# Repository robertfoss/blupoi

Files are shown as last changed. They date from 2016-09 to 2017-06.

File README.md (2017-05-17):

blupoi
======

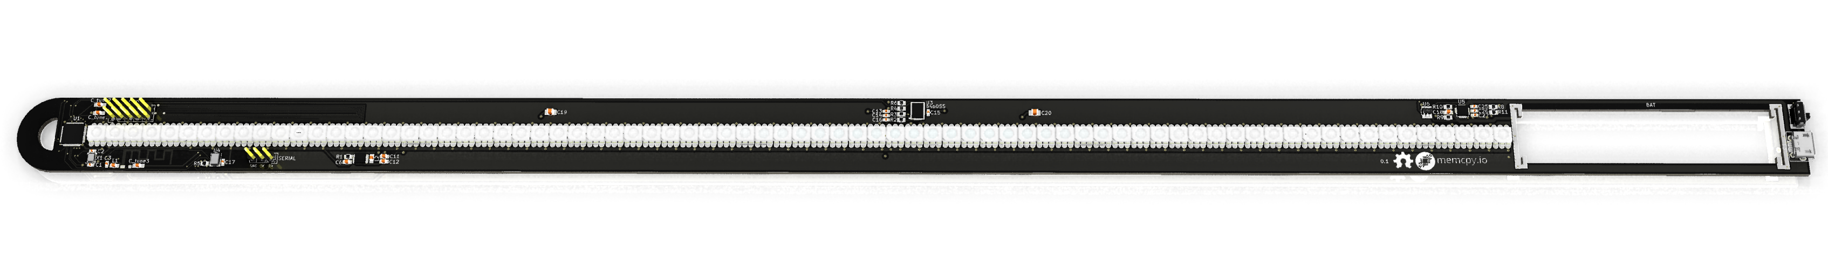
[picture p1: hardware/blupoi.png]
v0.1: render


TODO
----

Changes since v0.3:
 - 1uF 0402 caps not ordered
 * C27 pad has a large via in a pad
 * FIXED: MAX16054 Connect CLEAR to GND if unused.
 * FIXED: SIP32408 Footprint pinout was mirrored
 ? Change battery orientation, since spring should be on the top side but also on the gnd side of BAT
  - Maybe dont since VBAT would end up coming out in a place where it is not useful
 * X1 label covered by hole
 * X1 footprint larger than bom part?
 * C1/C2/C3 footprint is 0603 but bom is 0402
 * SWO header, change part and footprint to have only be connectable the 'right' way

Changes since v0.2:
 * FIXED: Replaced USB connector oval holes with round ones for improved fabricability
 * FIXED: Reflowed filled zones since KiCad somehow did it randomly wrong in v0.2
 * FIXED: R1 Move via further away from pad
 * FIXED: Move USB connector and power button to the side

Changes since v0.1:
 * FIXED: Battery compartment is not quite wide enough.
 * IGNORE: Battery compartment battery spring slot is:
   - 0.5mm too thin, should be 1.6mm
   - 0.5mm too slim, should me 17.75mm
 * FIXED: Spring slots lack copper on the back side
 * FIXED: +/- symbols on the battery silkscreen
 ? IGNORE: battery footprint 180 degrees

 * FIXED: U5/bq24075 EN1 is not pulled down
 * FIXED: U5/bq24075 sysoff turns charging off. Which is should never dd
   - Add separate add some kind of switch between u5 out and vin, controlled by button logic
   - Pull sysoff down
 * Add Load switch like Sip32431 - http://www.vishay.com/docs/66597/sip32431.pdf
   - But ~4.8A at @ 5V
   - SiP32101? No. Is LGA package
   - SiP32408? 3.5A probably ok since no usb port delivers that, and probable no battery either
     - http://www.vishay.com/docs/63717/sip32408.pdf

 * FIXED: Mic port hole is not drilled (hole too small?)
 * FIXED: Mic pads should probably be longer

 * FIXED: Move button footprint slightly closer to edge

 * FIXED: BNO055 pads should probable be longer

 * FIXED: Make logos bigger to make details visible

 * FIXED: Change L2 footprint from 0603 to 1206

 * Vin not connected on 3.3V regulator

 * FIXED: Add silkscreen saying:
   look at you, hacker, a pathetic creature of meat and bone. how can you compare yourself to a perfect immortal machine.

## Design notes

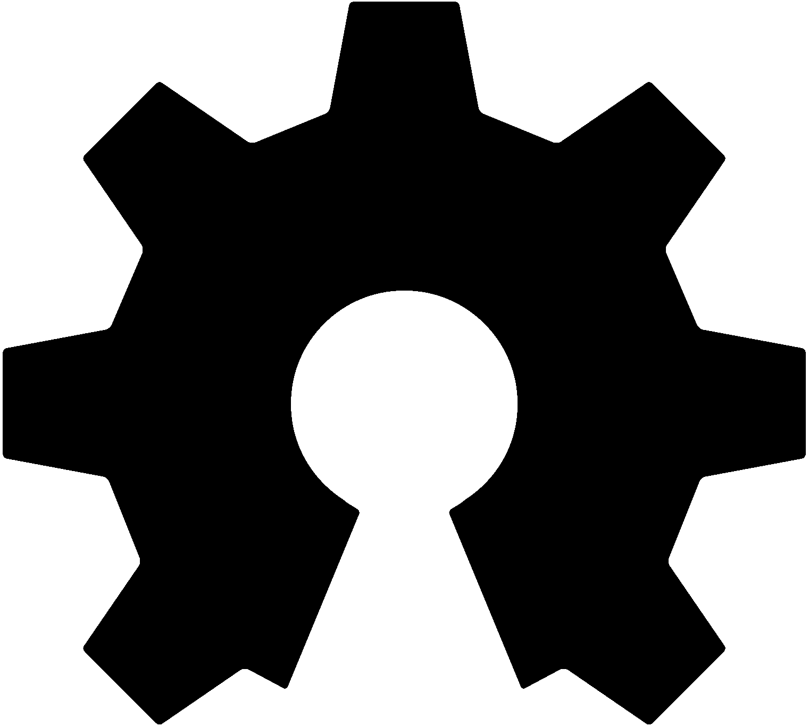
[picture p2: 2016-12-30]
hardware/graphics/oshw_crop_bw.png

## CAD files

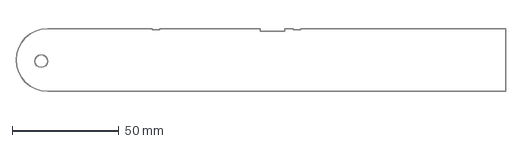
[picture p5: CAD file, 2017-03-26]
hardware/outline/outline_small_fat.dxf
229.7 x 29.5 mm

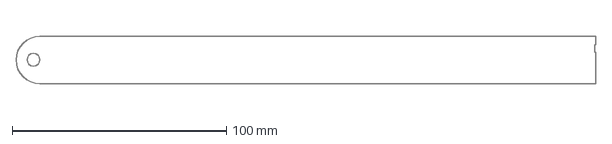
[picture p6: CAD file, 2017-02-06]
hardware/outline/outline_small.dxf
270.6 x 22.2 mm

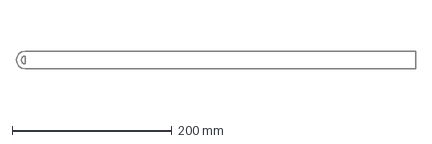
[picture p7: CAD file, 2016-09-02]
hardware/outline/outline.dxf
500.1 x 22.2 mm

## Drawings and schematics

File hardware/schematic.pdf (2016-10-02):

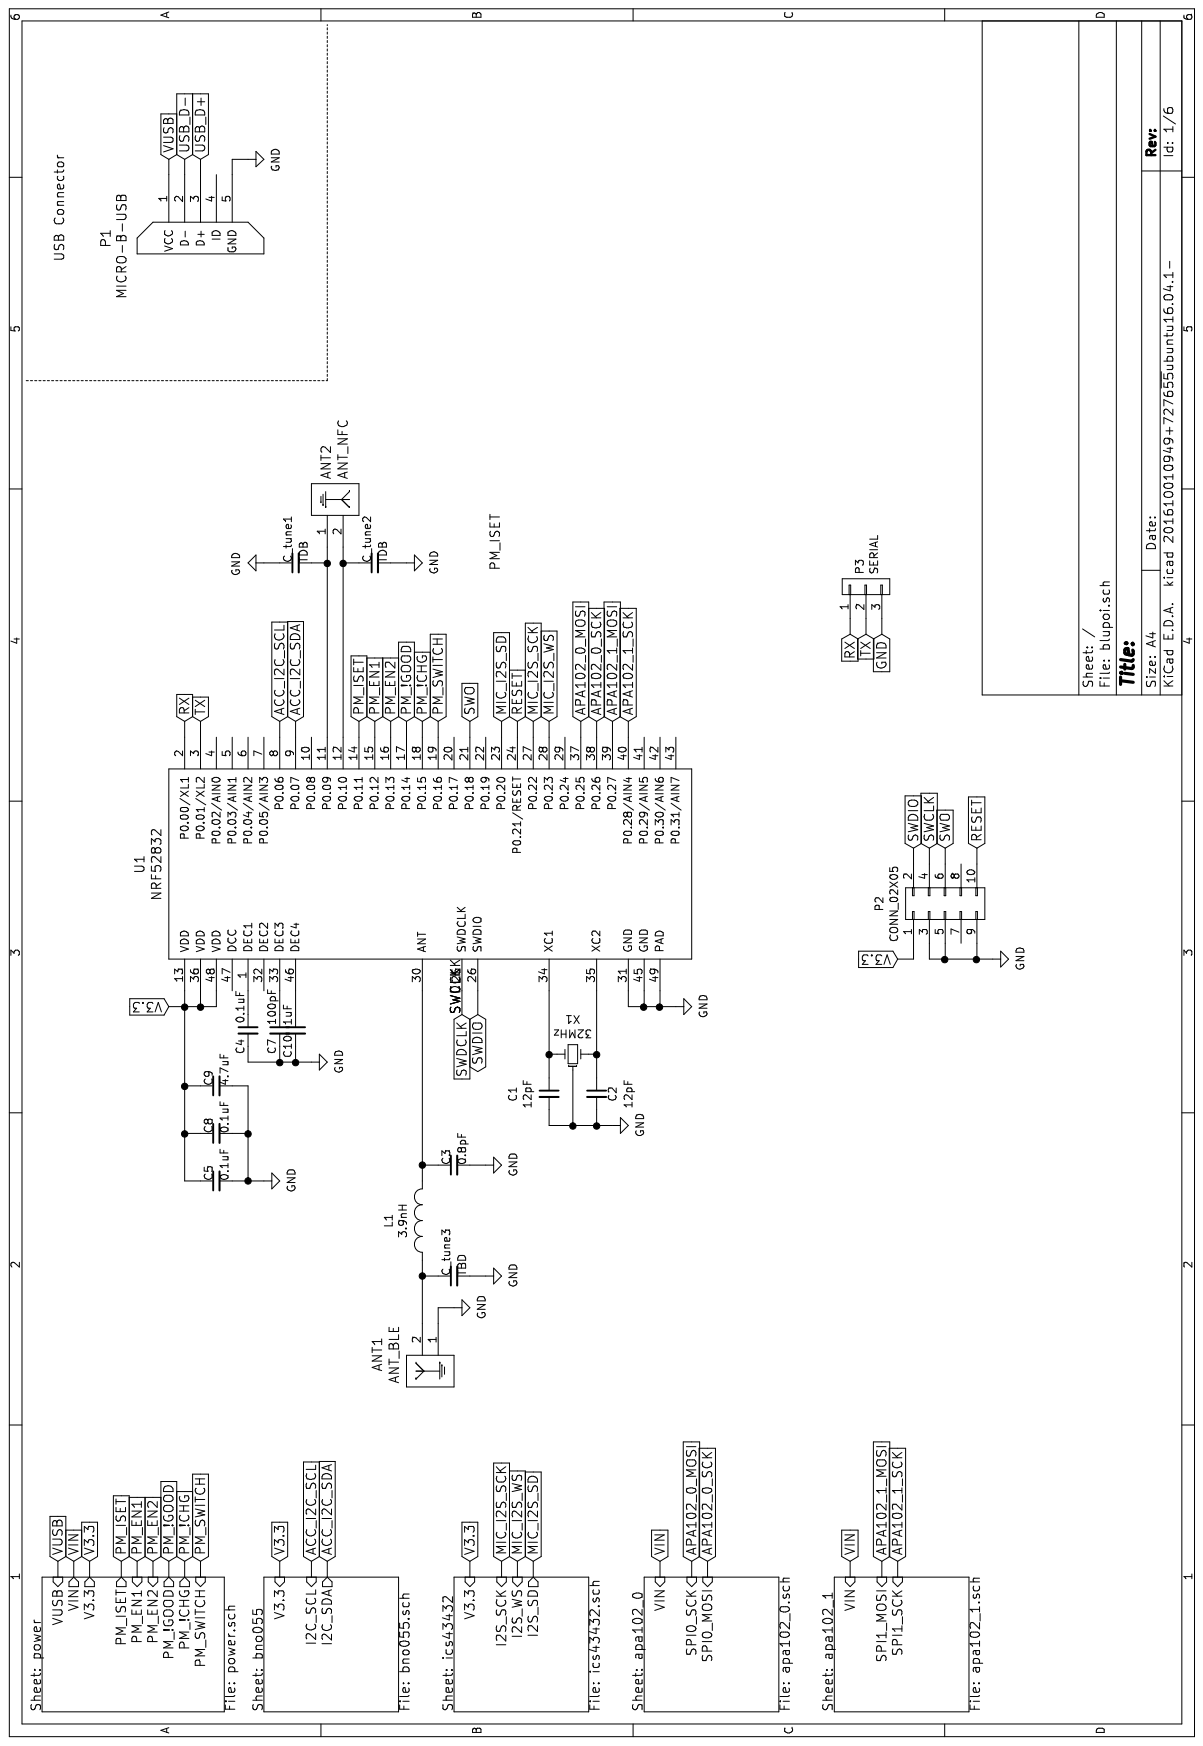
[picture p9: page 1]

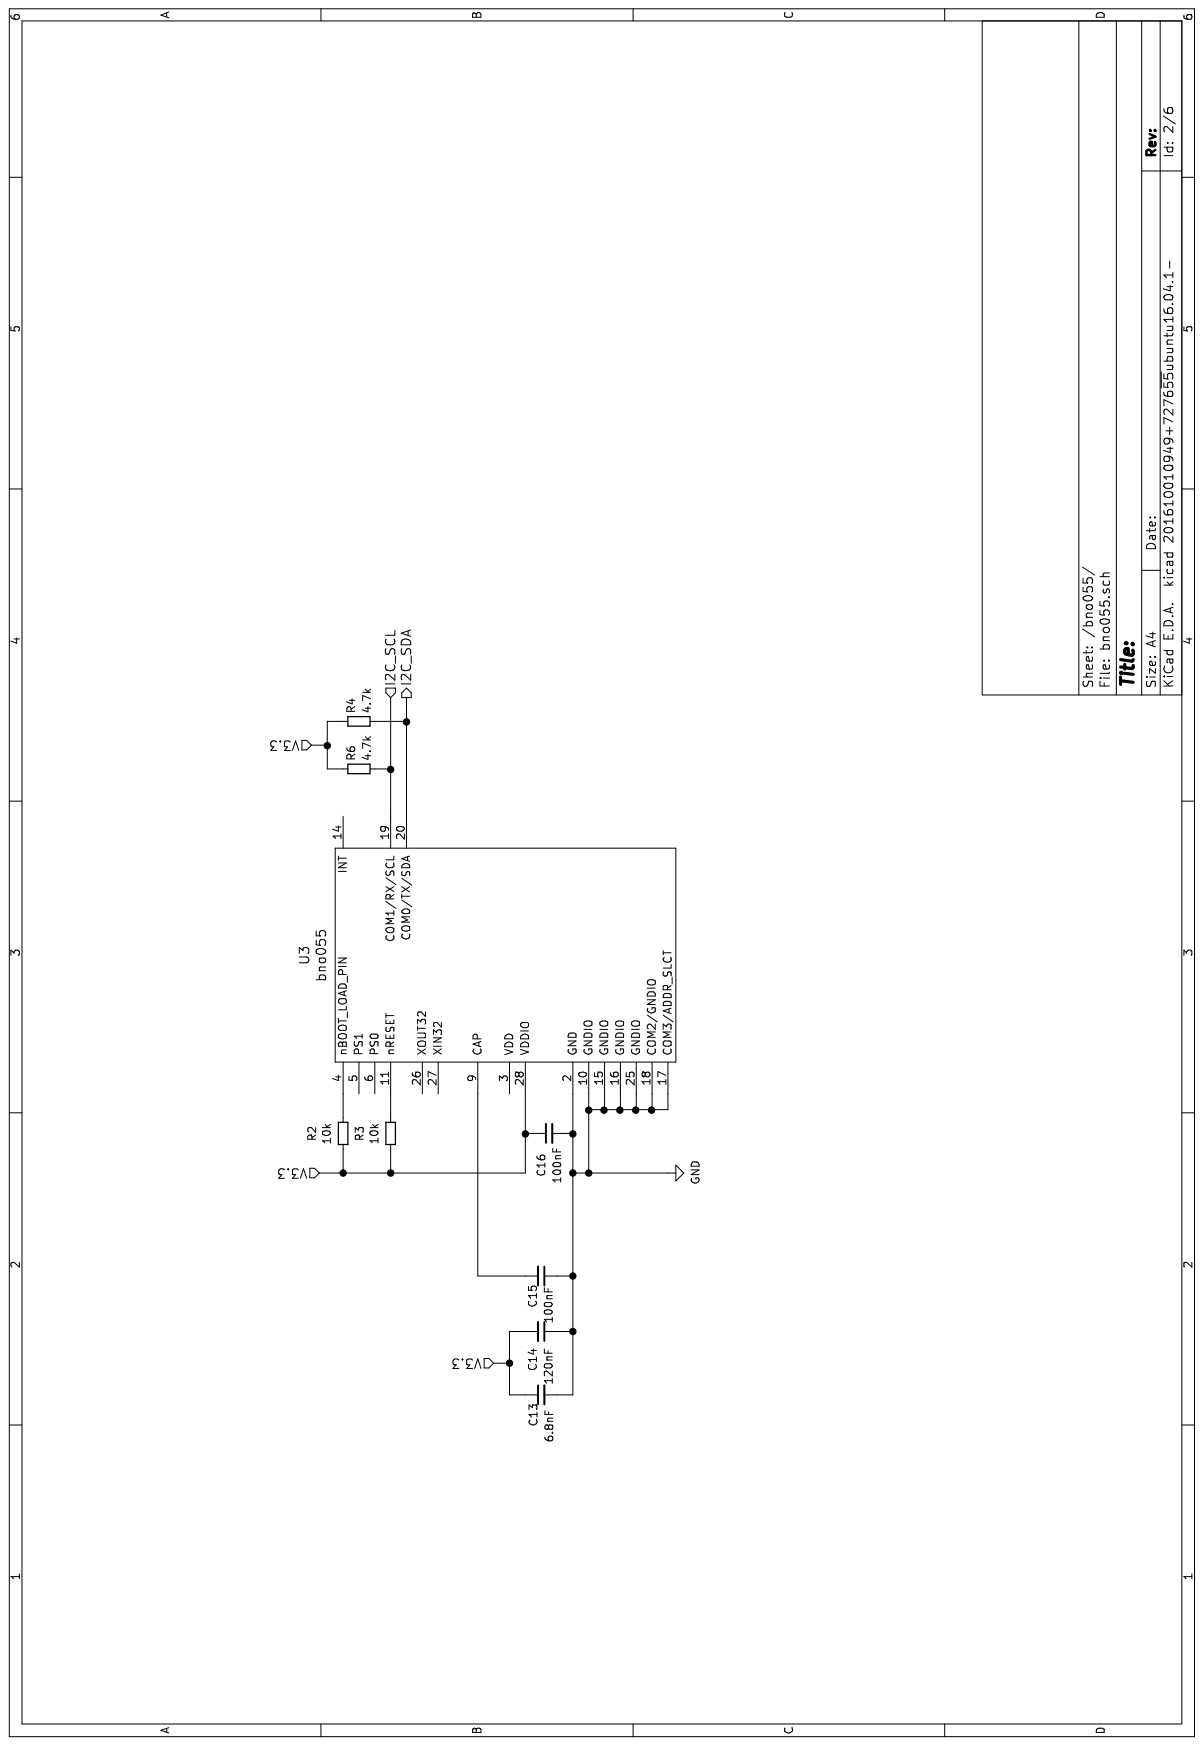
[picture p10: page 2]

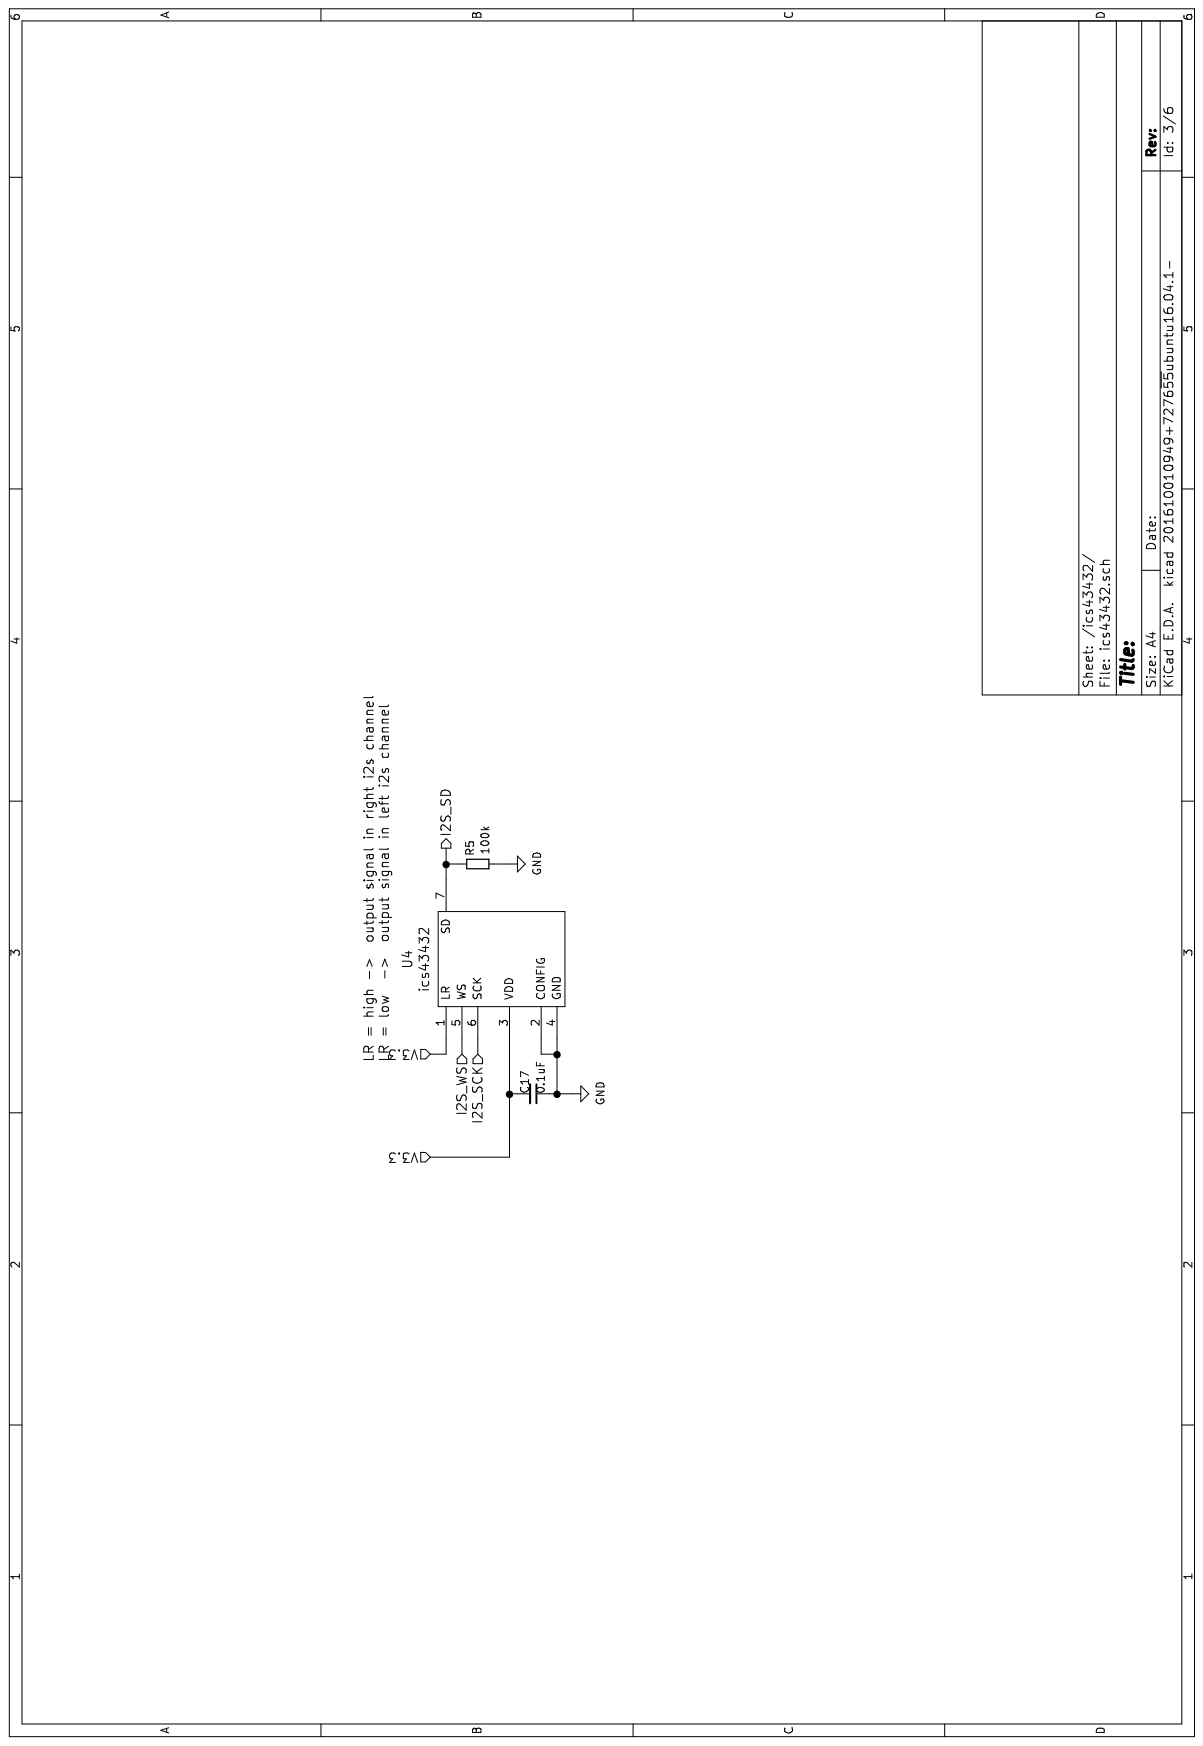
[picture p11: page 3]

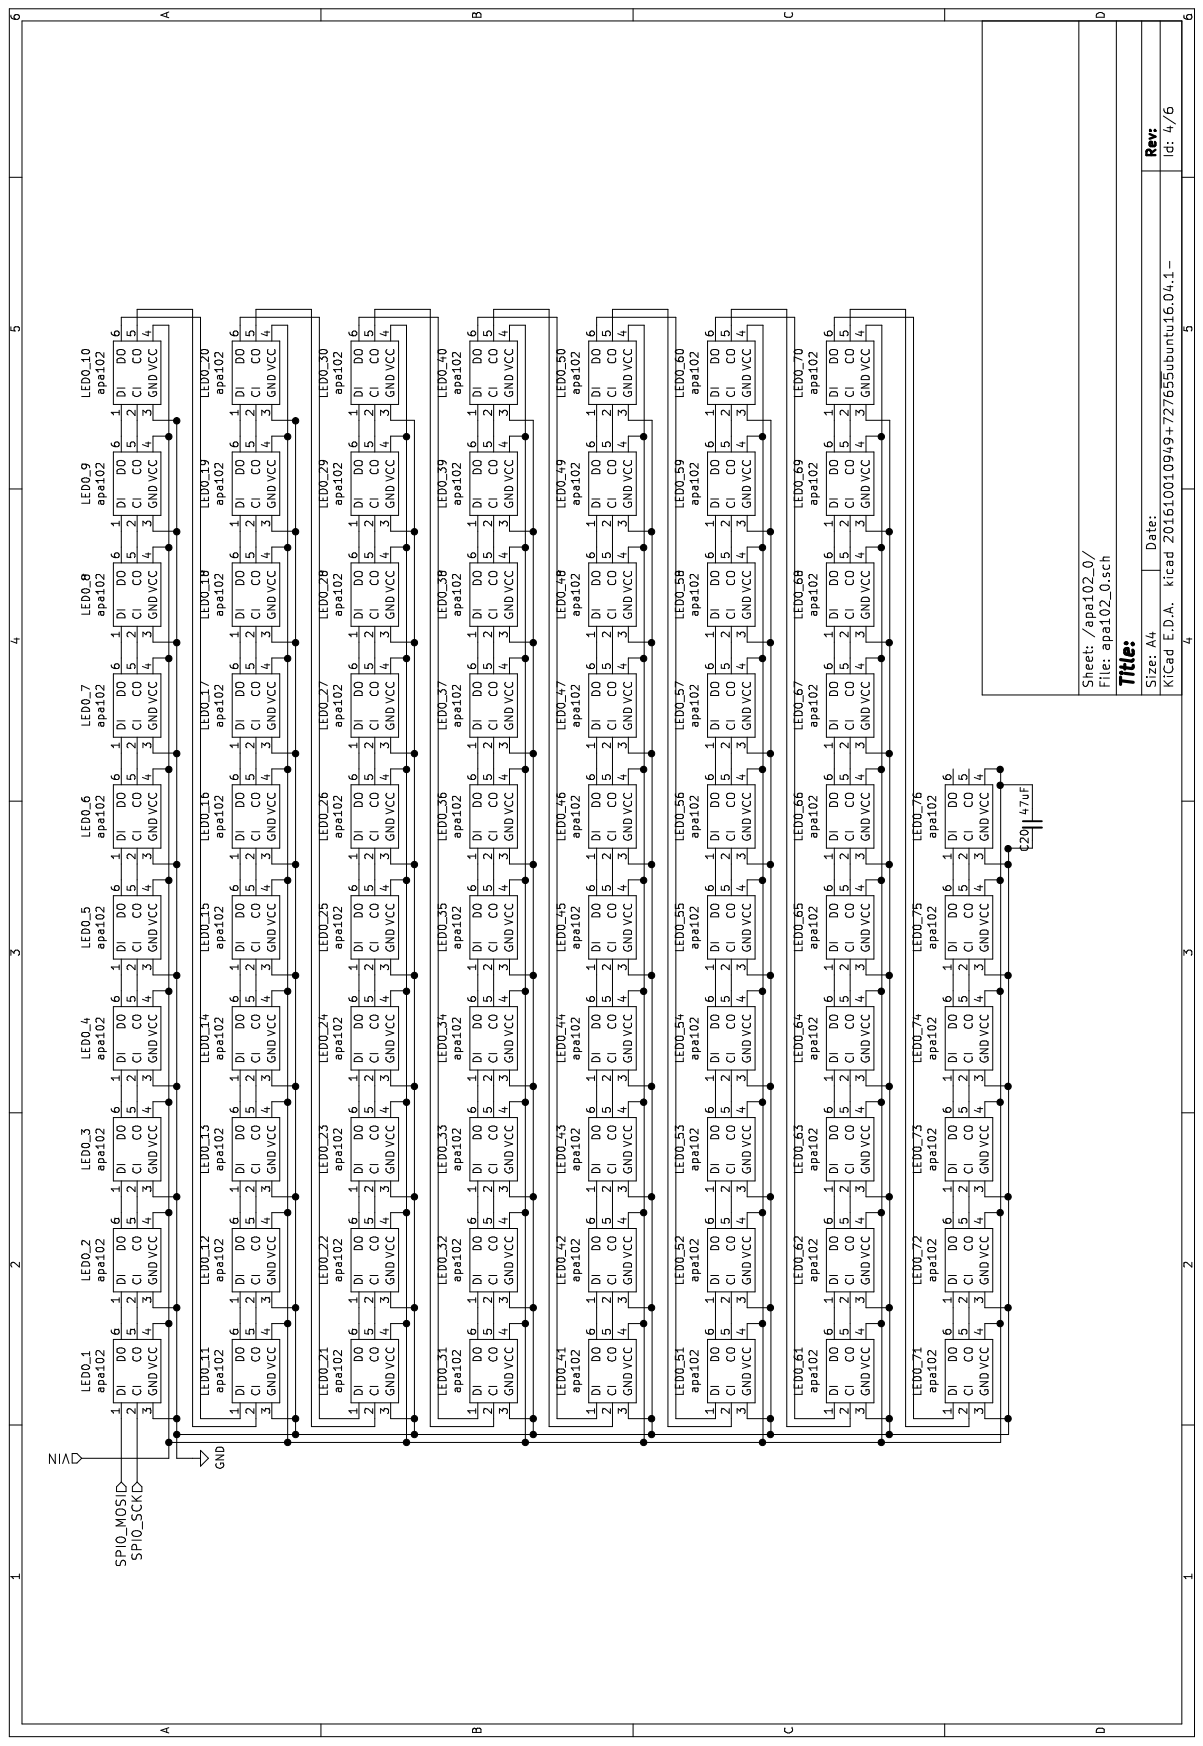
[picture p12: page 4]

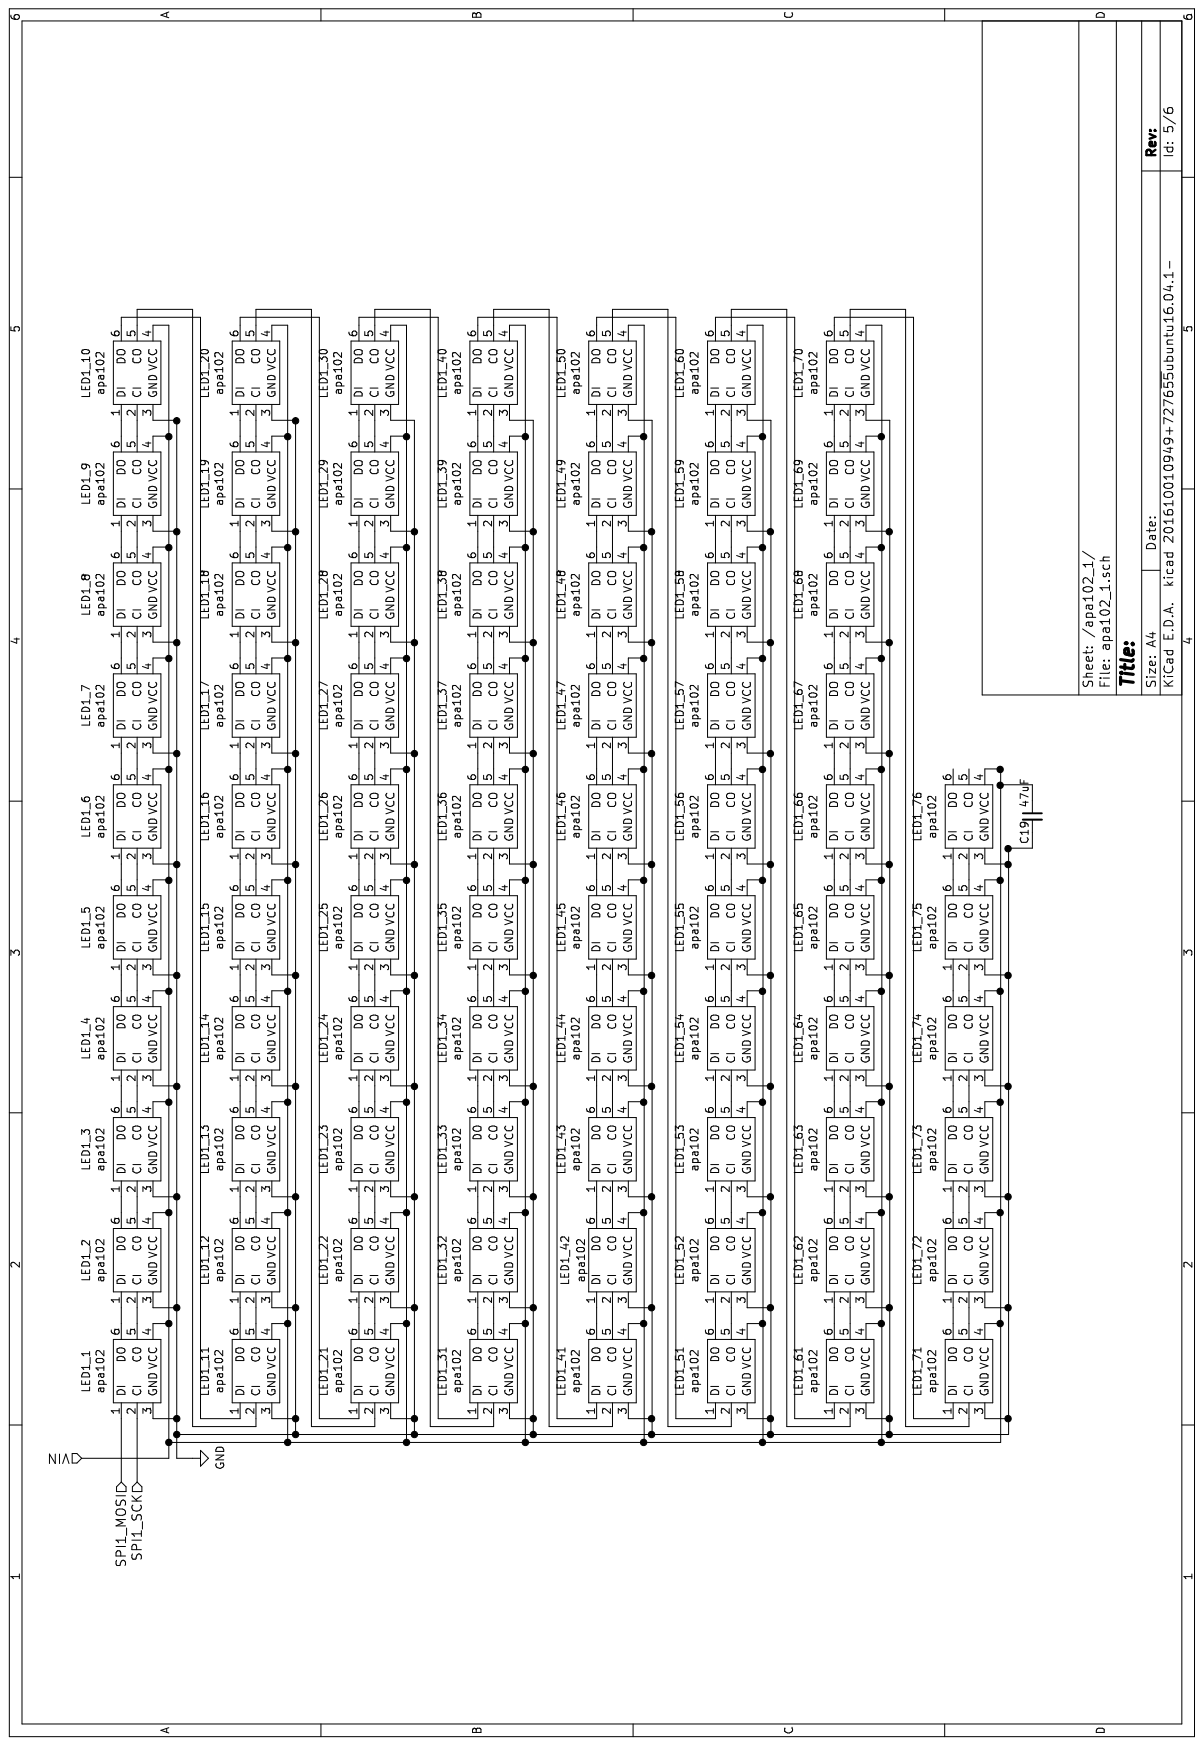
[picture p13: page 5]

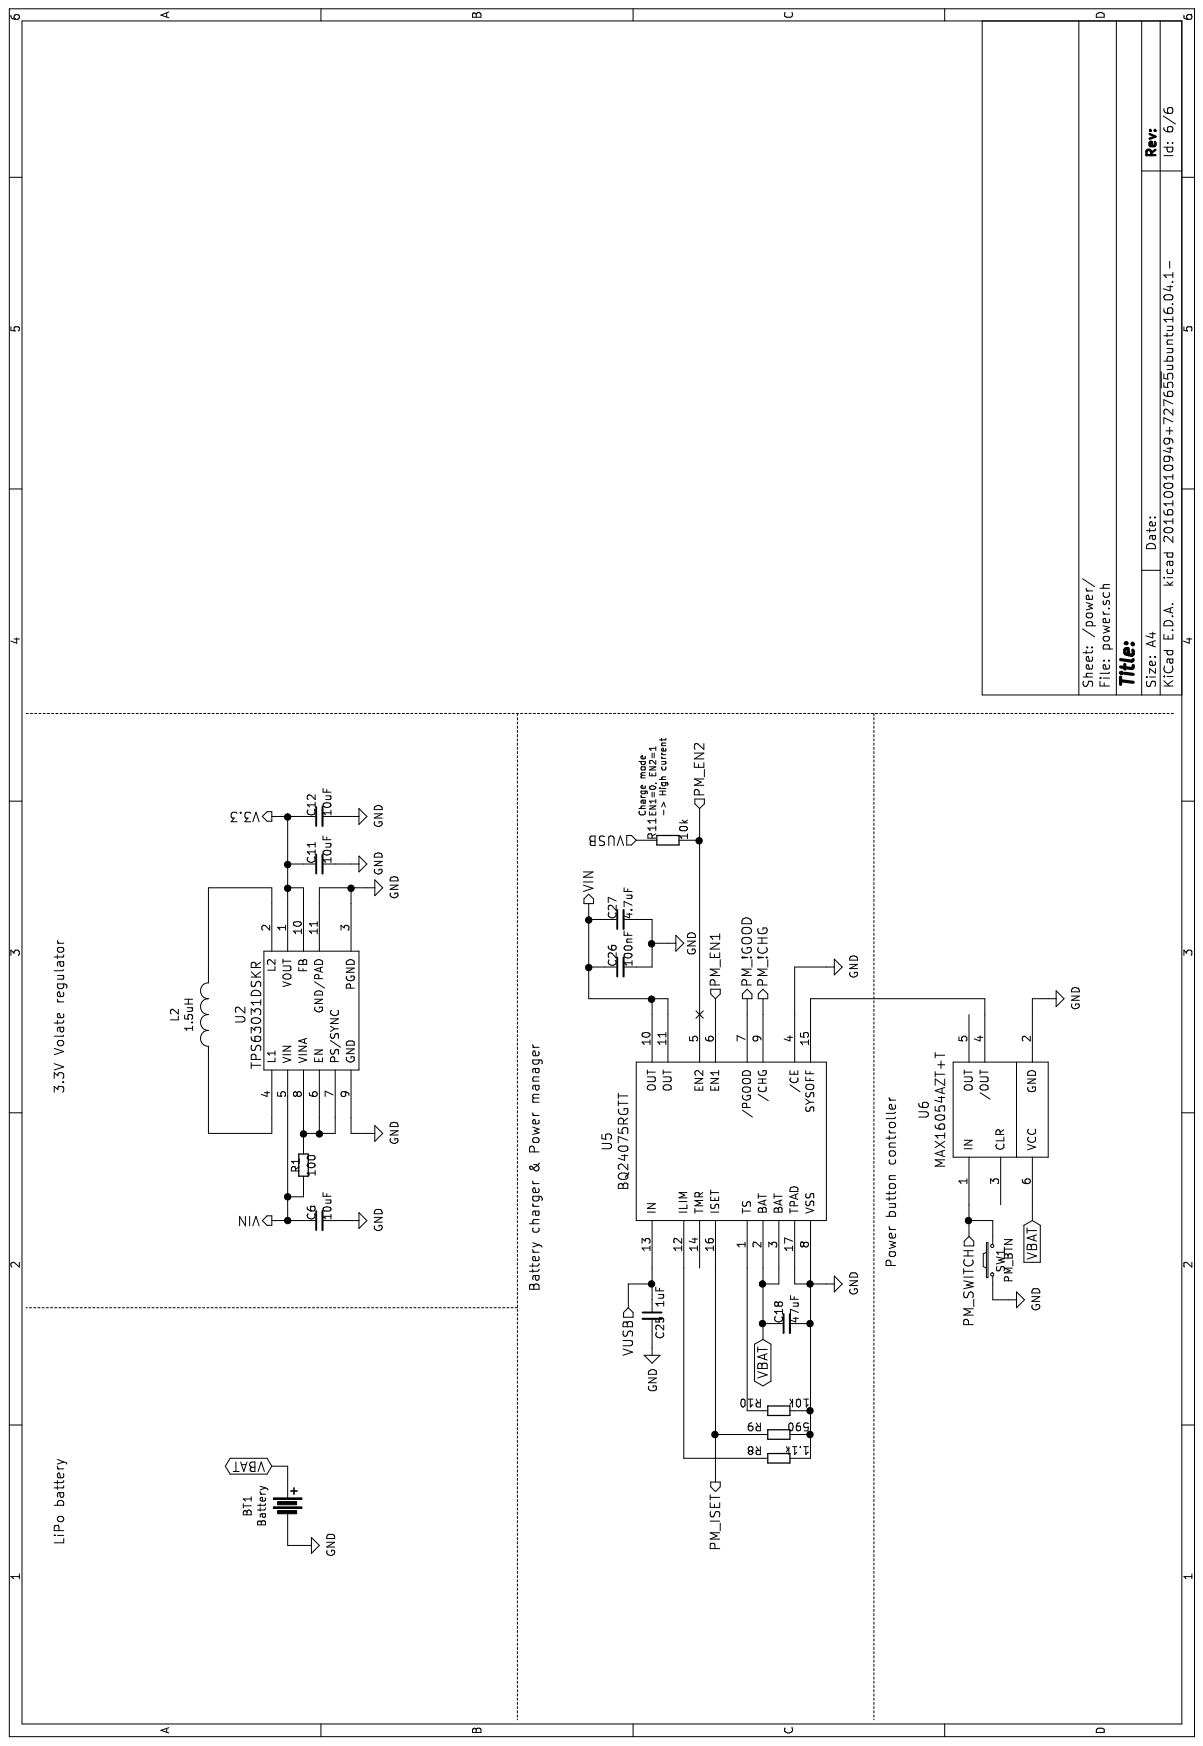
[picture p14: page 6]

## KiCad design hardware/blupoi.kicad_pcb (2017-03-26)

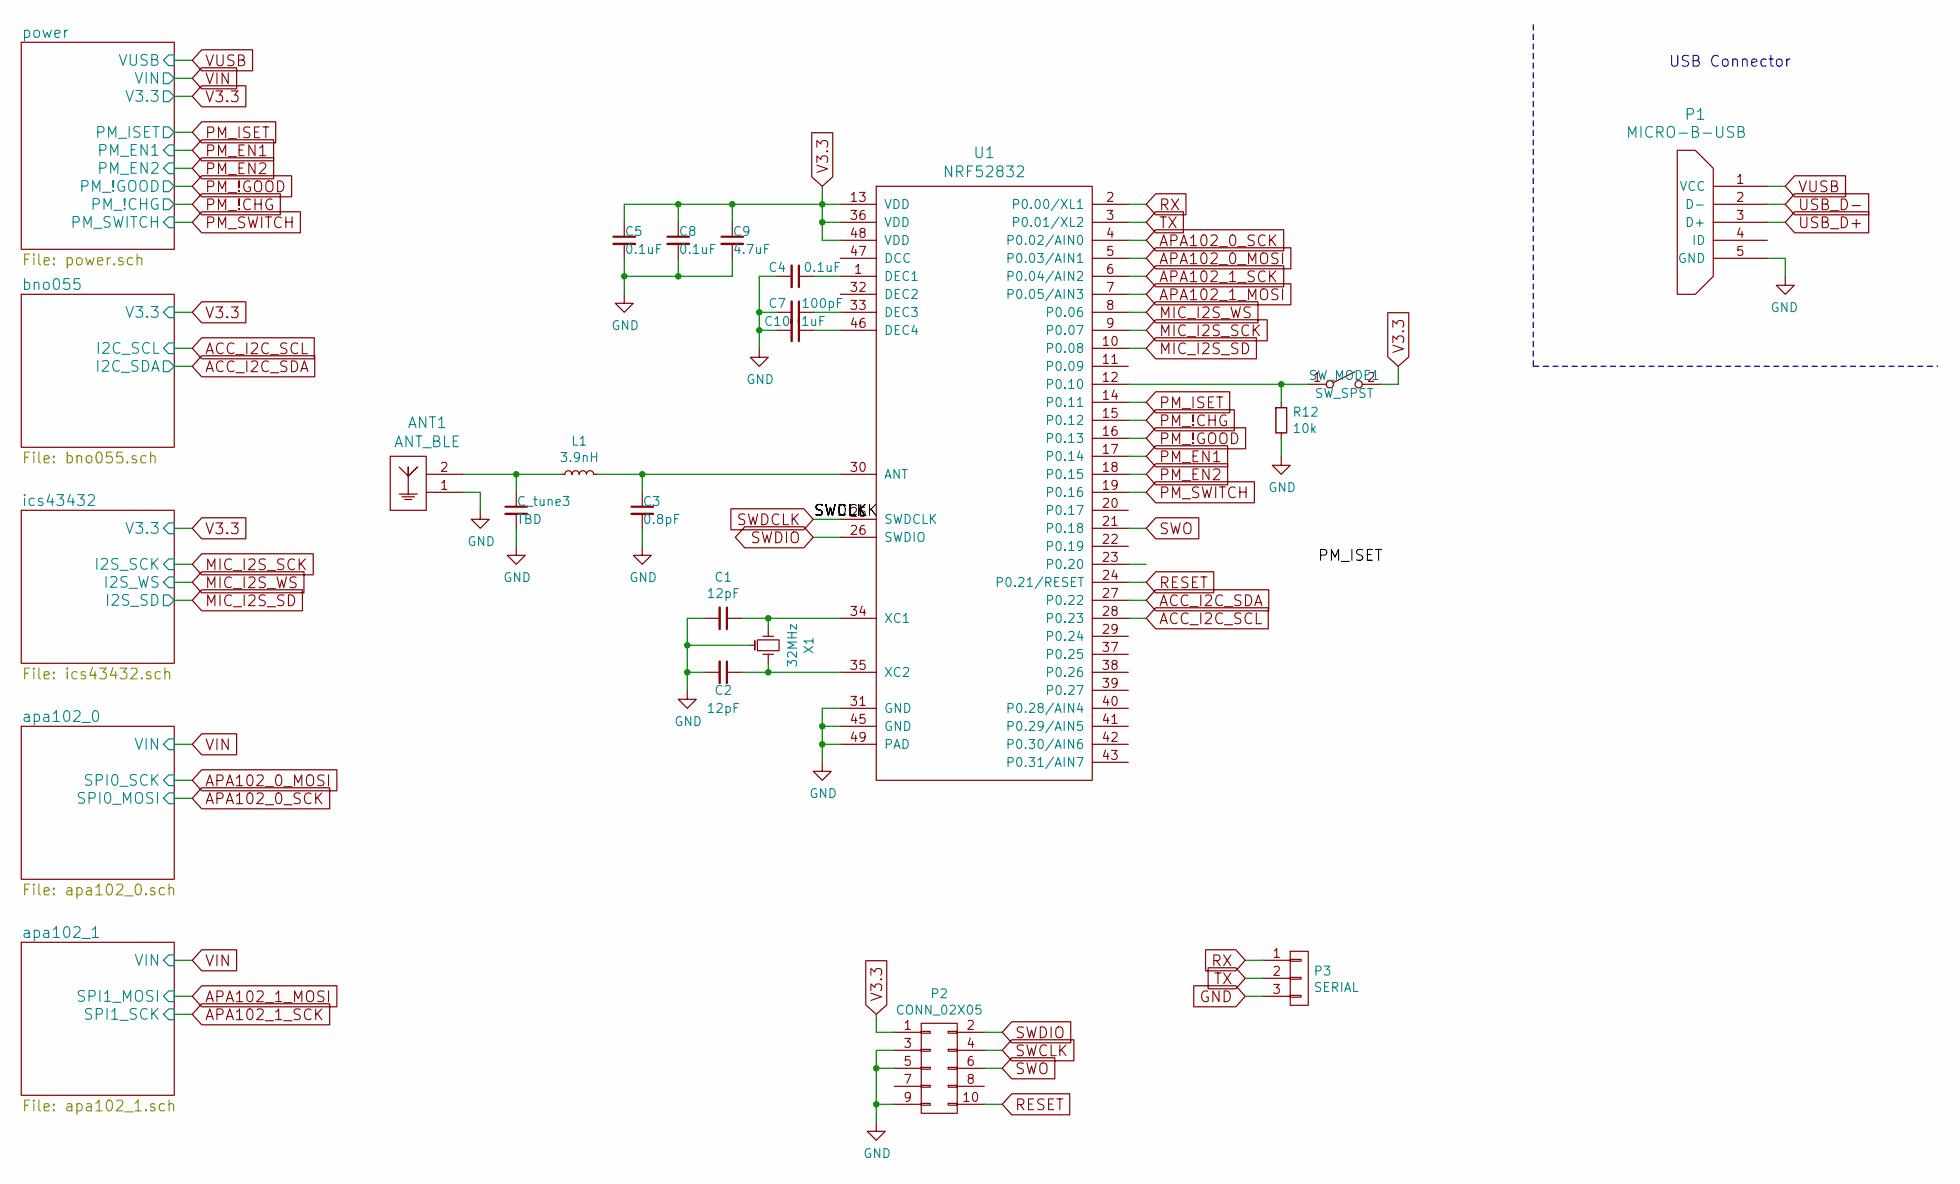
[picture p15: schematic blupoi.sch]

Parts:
ANT1: ANT_BLE; ti-an043-antenna
C1, C2: 12pF; C_0402
C3: 0.8pF; C_0402; MFG Part Num Value
C4: 0.1uF; C_0402
C5, C8: 0.1uF; C_0402; MFG Part Num Value
C7: 100pF; C_0402; MFG Part Num Value
C9: 4.7uF; C_0603; MFG Part Num Value
C10: 1uF; C_0603; MFG Part Num Value
C_tune3: TBD; C_0603_HandSoldering; MFG Part Num Value
L1: 3.9nH; C_0402
P1: MICRO-B-USB; USB_Micro-B
P2: CONN_02X05; Pin_Header_Straight_2x05
P3: SERIAL; Pin_Header_Straight_1x03
R12: 10k; R_0603
SW_MODE1: SW_SPST; KSS241GLFS
U1: NRF52832; UQFN-48-1EP_6x6mm_Pitch0.4mm
X1: 32MHz; XTAL2016; MFG Part Num Value

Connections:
ACC_I2C_SCL: U1.28 (P0.23); also elsewhere on the board
ACC_I2C_SDA: U1.27 (P0.22); also elsewhere on the board
APA102_0_MOSI: U1.5 (P0.03/AIN1); also elsewhere on the board
APA102_0_SCK: U1.4 (P0.02/AIN0); also elsewhere on the board
APA102_1_MOSI: U1.7 (P0.05/AIN3); also elsewhere on the board
APA102_1_SCK: U1.6 (P0.04/AIN2); also elsewhere on the board
GND: ANT1.1, C1.2, C2.2, C3.2, C4.2, C5.2, C7.2, C8.2, C9.2, C10.2, C_tune3.2, P1.5 (GND), P2.3, P2.5, P2.9, R12.2, U1.31 (GND), U1.45 (GND), U1.49 (PAD), X1.3; also elsewhere on the board
MIC_I2S_SCK: U1.9 (P0.07); also elsewhere on the board
MIC_I2S_SD: U1.10 (P0.08); also elsewhere on the board
MIC_I2S_WS: U1.8 (P0.06); also elsewhere on the board
unnamed: ANT1.2, C_tune3.1, L1.1
unnamed: C1.1, U1.34 (XC1), X1.2
unnamed: C2.1, U1.35 (XC2), X1.1
unnamed: C3.1, L1.2, U1.30 (ANT)
unnamed: C4.1, U1.1 (DEC1)
unnamed: C7.1, U1.33 (DEC3)
unnamed: C10.1, U1.46 (DEC4)
unnamed: R12.1, SW_MODE1.1 (A), U1.12 (P0.10)
PM_!CHG: U1.15 (P0.12); also elsewhere on the board
PM_!GOOD: U1.16 (P0.13); also elsewhere on the board
PM_EN1: U1.17 (P0.14); also elsewhere on the board
PM_EN2: U1.18 (P0.15); also elsewhere on the board
PM_ISET: U1.14 (P0.11); also elsewhere on the board
PM_SWITCH: U1.19 (P0.16); also elsewhere on the board
RESET: P2.10, U1.24 (P0.21/RESET); also elsewhere on the board
RX: P3.1, U1.2 (P0.00/XL1); also elsewhere on the board
SWCLK: U1.25 (SWDCLK); also elsewhere on the board
SWDIO: P2.2, U1.26 (SWDIO); also elsewhere on the board
SWO: P2.6, U1.21 (P0.18); also elsewhere on the board
TX: P3.2, U1.3 (P0.01/XL2); also elsewhere on the board
USB_D+: P1.3 (D+)
USB_D-: P1.2 (D-)
V3.3: C5.1, C8.1, C9.1, P2.1, SW_MODE1.2 (B), U1.13 (VDD), U1.36 (VDD), U1.48 (VDD); also elsewhere on the board
VUSB: P1.1 (VCC); also elsewhere on the board

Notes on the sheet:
USB Connector

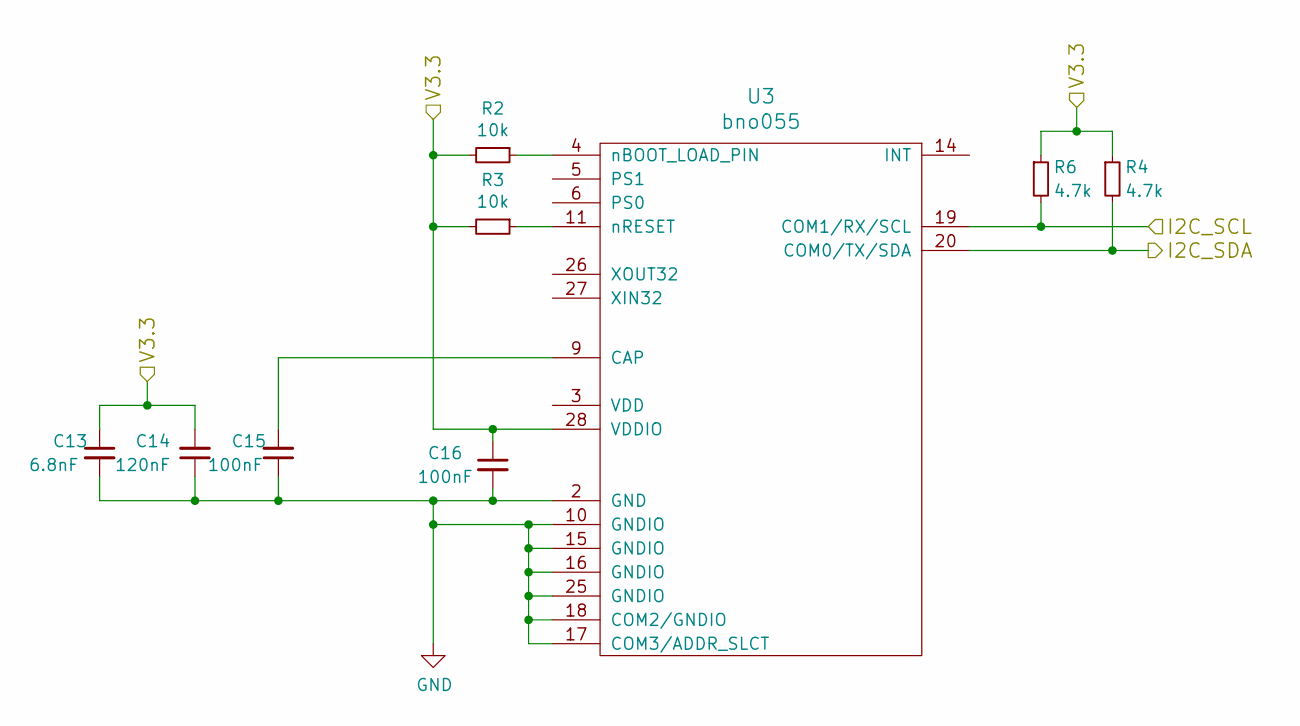
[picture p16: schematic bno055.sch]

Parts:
C13: 6.8nF; C_0402
C14: 120nF; C_0402
C15, C16: 100nF; C_0402
R2, R3: 10k; R_0603
R4, R6: 4.7k; R_0603
U3: bno055

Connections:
ACC_I2C_SCL: R6.2, U3.19 (COM1/RX/SCL); also elsewhere on the board
ACC_I2C_SDA: R4.2, U3.20 (COM0/TX/SDA); also elsewhere on the board
GND: C13.2, C14.1, C15.1, C16.2, U3.2 (GND), U3.10 (GNDIO), U3.15 (GNDIO), U3.16 (GNDIO), U3.17 (COM3/ADDR_SLCT), U3.18 (COM2/GNDIO), U3.25 (GNDIO); also elsewhere on the board
unnamed: C15.2, U3.9 (CAP)
unnamed: R2.1, U3.4 (nBOOT_LOAD_PIN)
unnamed: R3.1, U3.11 (nRESET)
V3.3: C13.1, C14.2, C16.1, R2.2, R3.2, R4.1, R6.1, U3.28 (VDDIO); also elsewhere on the board

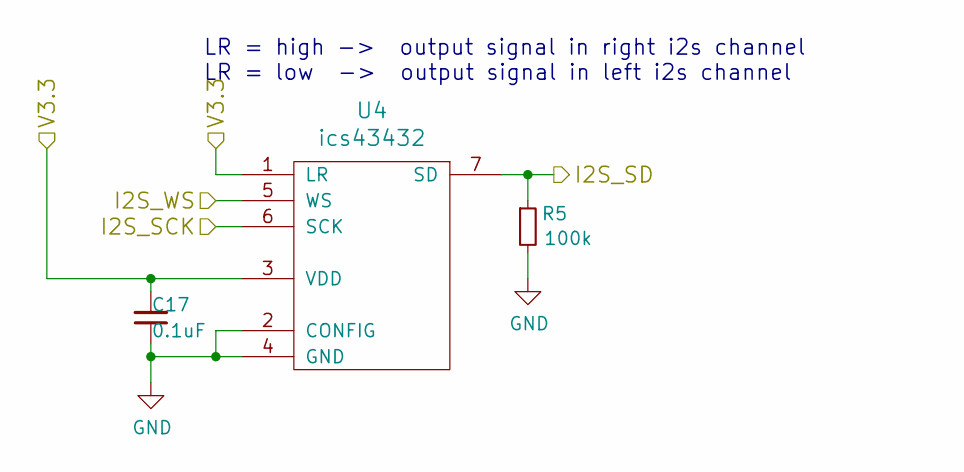
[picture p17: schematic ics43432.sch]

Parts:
C17: 0.1uF; C_0402
R5: 100k; R_0603
U4: ics43432

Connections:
GND: C17.1, R5.2, U4.2 (CONFIG), U4.4 (GND); also elsewhere on the board
MIC_I2S_SCK: U4.6 (SCK); also elsewhere on the board
MIC_I2S_SD: R5.1, U4.7 (SD); also elsewhere on the board
MIC_I2S_WS: U4.5 (WS); also elsewhere on the board
V3.3: C17.2, U4.1 (LR), U4.3 (VDD); also elsewhere on the board

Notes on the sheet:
LR = high -> output signal in right i2s channel LR = low -> output signal in left i2s channel

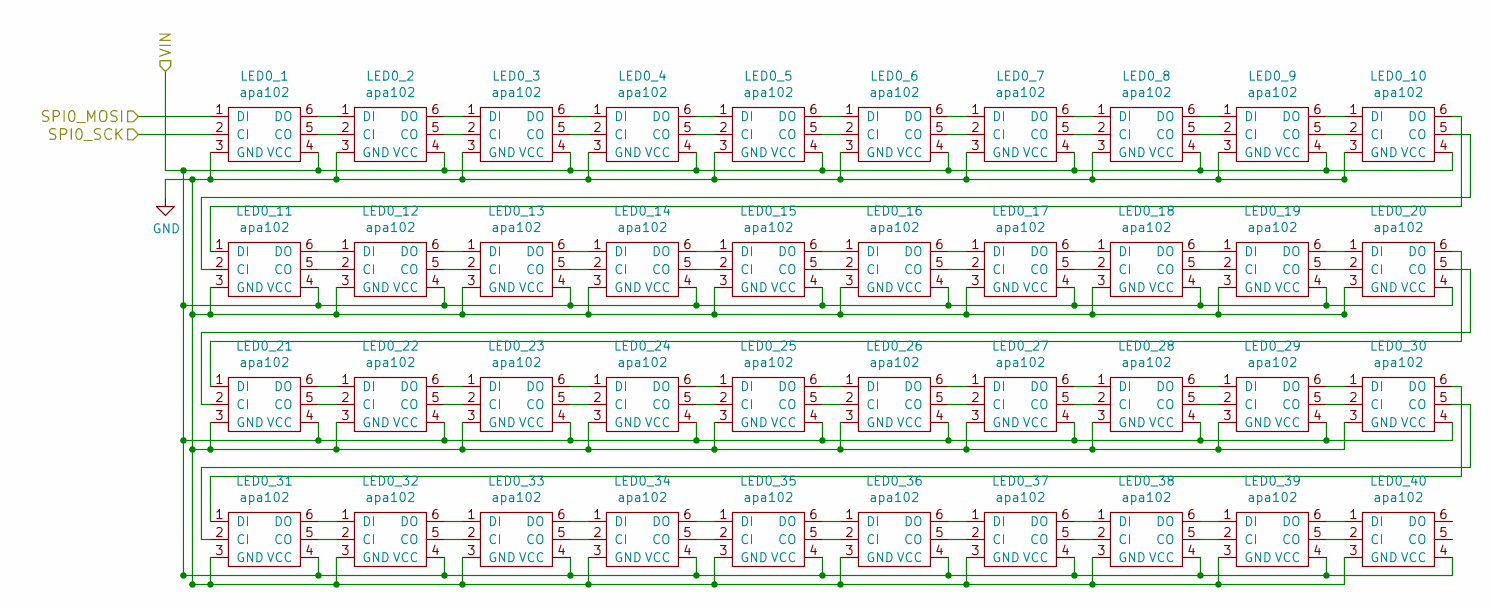
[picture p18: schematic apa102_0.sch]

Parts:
LED0_1, LED0_2, LED0_3, LED0_4, LED0_5, LED0_6, LED0_7, LED0_8, LED0_9, LED0_10, LED0_11, LED0_12, LED0_13, LED0_14, LED0_15, LED0_16, LED0_17, LED0_18, LED0_19, LED0_20, LED0_21, LED0_22, LED0_23, LED0_24, LED0_25, LED0_26, LED0_27, LED0_28, LED0_29, LED0_30, LED0_31, LED0_32, LED0_33, LED0_34, LED0_35, LED0_36, LED0_37, LED0_38, LED0_39, LED0_40: apa102

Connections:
APA102_0_MOSI: LED0_1.2 (CI); also elsewhere on the board
APA102_0_SCK: LED0_1.1 (DI); also elsewhere on the board
GND: LED0_1.3 (GND), LED0_2.3 (GND), LED0_3.3 (GND), LED0_4.3 (GND), LED0_5.3 (GND), LED0_6.3 (GND), LED0_7.3 (GND), LED0_8.3 (GND), LED0_9.3 (GND), LED0_10.3 (GND), LED0_11.3 (GND), LED0_12.3 (GND), LED0_13.3 (GND), LED0_14.3 (GND), LED0_15.3 (GND), LED0_16.3 (GND), LED0_17.3 (GND), LED0_18.3 (GND), LED0_19.3 (GND), LED0_20.3 (GND), LED0_21.3 (GND), LED0_22.3 (GND), LED0_23.3 (GND), LED0_24.3 (GND), LED0_25.3 (GND), LED0_26.3 (GND), LED0_27.3 (GND), LED0_28.3 (GND), LED0_29.3 (GND), LED0_30.3 (GND), LED0_31.3 (GND), LED0_32.3 (GND), LED0_33.3 (GND), LED0_34.3 (GND), LED0_35.3 (GND), LED0_36.3 (GND), LED0_37.3 (GND), LED0_38.3 (GND), LED0_39.3 (GND), LED0_40.3 (GND); also elsewhere on the board
unnamed: LED0_1.5 (CO), LED0_2.2 (CI)
unnamed: LED0_1.6 (DO), LED0_2.1 (DI)
unnamed: LED0_2.5 (CO), LED0_3.2 (CI)
unnamed: LED0_2.6 (DO), LED0_3.1 (DI)
unnamed: LED0_3.5 (CO), LED0_4.2 (CI)
unnamed: LED0_3.6 (DO), LED0_4.1 (DI)
unnamed: LED0_4.5 (CO), LED0_5.2 (CI)
unnamed: LED0_4.6 (DO), LED0_5.1 (DI)
unnamed: LED0_5.5 (CO), LED0_6.2 (CI)
unnamed: LED0_5.6 (DO), LED0_6.1 (DI)
unnamed: LED0_6.5 (CO), LED0_7.2 (CI)
unnamed: LED0_6.6 (DO), LED0_7.1 (DI)
unnamed: LED0_7.5 (CO), LED0_8.2 (CI)
unnamed: LED0_7.6 (DO), LED0_8.1 (DI)
unnamed: LED0_8.5 (CO), LED0_9.2 (CI)
unnamed: LED0_8.6 (DO), LED0_9.1 (DI)
unnamed: LED0_9.6 (DO), LED0_10.1 (DI)
unnamed: LED0_9.5 (CO), LED0_10.2 (CI)
unnamed: LED0_10.5 (CO), LED0_11.2 (CI)
unnamed: LED0_10.6 (DO), LED0_11.1 (DI)
unnamed: LED0_11.5 (CO), LED0_12.2 (CI)
unnamed: LED0_11.6 (DO), LED0_12.1 (DI)
unnamed: LED0_12.5 (CO), LED0_13.2 (CI)
unnamed: LED0_12.6 (DO), LED0_13.1 (DI)
unnamed: LED0_13.5 (CO), LED0_14.2 (CI)
unnamed: LED0_13.6 (DO), LED0_14.1 (DI)
unnamed: LED0_14.5 (CO), LED0_15.2 (CI)
unnamed: LED0_14.6 (DO), LED0_15.1 (DI)
unnamed: LED0_15.5 (CO), LED0_16.2 (CI)
unnamed: LED0_15.6 (DO), LED0_16.1 (DI)
unnamed: LED0_16.5 (CO), LED0_17.2 (CI)
unnamed: LED0_16.6 (DO), LED0_17.1 (DI)
unnamed: LED0_17.5 (CO), LED0_18.2 (CI)
unnamed: LED0_17.6 (DO), LED0_18.1 (DI)
unnamed: LED0_18.5 (CO), LED0_19.2 (CI)
unnamed: LED0_18.6 (DO), LED0_19.1 (DI)
unnamed: LED0_19.5 (CO), LED0_20.2 (CI)
unnamed: LED0_19.6 (DO), LED0_20.1 (DI)
unnamed: LED0_20.5 (CO), LED0_21.2 (CI)
unnamed: LED0_20.6 (DO), LED0_21.1 (DI)
unnamed: LED0_21.5 (CO), LED0_22.2 (CI)
unnamed: LED0_21.6 (DO), LED0_22.1 (DI)
unnamed: LED0_22.5 (CO), LED0_23.2 (CI)
unnamed: LED0_22.6 (DO), LED0_23.1 (DI)
unnamed: LED0_23.5 (CO), LED0_24.2 (CI)
unnamed: LED0_23.6 (DO), LED0_24.1 (DI)
unnamed: LED0_24.5 (CO), LED0_25.2 (CI)
unnamed: LED0_24.6 (DO), LED0_25.1 (DI)
unnamed: LED0_25.5 (CO), LED0_26.2 (CI)
unnamed: LED0_25.6 (DO), LED0_26.1 (DI)
unnamed: LED0_26.5 (CO), LED0_27.2 (CI)
unnamed: LED0_26.6 (DO), LED0_27.1 (DI)
unnamed: LED0_27.5 (CO), LED0_28.2 (CI)
unnamed: LED0_27.6 (DO), LED0_28.1 (DI)
unnamed: LED0_28.5 (CO), LED0_29.2 (CI)
unnamed: LED0_28.6 (DO), LED0_29.1 (DI)
unnamed: LED0_29.5 (CO), LED0_30.2 (CI)
unnamed: LED0_29.6 (DO), LED0_30.1 (DI)
unnamed: LED0_30.5 (CO), LED0_31.2 (CI)
unnamed: LED0_30.6 (DO), LED0_31.1 (DI)
unnamed: LED0_31.5 (CO), LED0_32.2 (CI)
unnamed: LED0_31.6 (DO), LED0_32.1 (DI)
unnamed: LED0_32.5 (CO), LED0_33.2 (CI)
unnamed: LED0_32.6 (DO), LED0_33.1 (DI)
unnamed: LED0_33.5 (CO), LED0_34.2 (CI)
unnamed: LED0_33.6 (DO), LED0_34.1 (DI)
unnamed: LED0_34.5 (CO), LED0_35.2 (CI)
unnamed: LED0_34.6 (DO), LED0_35.1 (DI)
unnamed: LED0_35.5 (CO), LED0_36.2 (CI)
unnamed: LED0_35.6 (DO), LED0_36.1 (DI)
unnamed: LED0_36.5 (CO), LED0_37.2 (CI)
unnamed: LED0_36.6 (DO), LED0_37.1 (DI)
unnamed: LED0_37.5 (CO), LED0_38.2 (CI)
unnamed: LED0_37.6 (DO), LED0_38.1 (DI)
unnamed: LED0_38.5 (CO), LED0_39.2 (CI)
unnamed: LED0_38.6 (DO), LED0_39.1 (DI)
unnamed: LED0_39.5 (CO), LED0_40.2 (CI)
unnamed: LED0_39.6 (DO), LED0_40.1 (DI)
VIN: LED0_1.4 (VCC), LED0_2.4 (VCC), LED0_3.4 (VCC), LED0_4.4 (VCC), LED0_5.4 (VCC), LED0_6.4 (VCC), LED0_7.4 (VCC), LED0_8.4 (VCC), LED0_9.4 (VCC), LED0_10.4 (VCC), LED0_11.4 (VCC), LED0_12.4 (VCC), LED0_13.4 (VCC), LED0_14.4 (VCC), LED0_15.4 (VCC), LED0_16.4 (VCC), LED0_17.4 (VCC), LED0_18.4 (VCC), LED0_19.4 (VCC), LED0_20.4 (VCC), LED0_21.4 (VCC), LED0_22.4 (VCC), LED0_23.4 (VCC), LED0_24.4 (VCC), LED0_25.4 (VCC), LED0_26.4 (VCC), LED0_27.4 (VCC), LED0_28.4 (VCC), LED0_29.4 (VCC), LED0_30.4 (VCC), LED0_31.4 (VCC), LED0_32.4 (VCC), LED0_33.4 (VCC), LED0_34.4 (VCC), LED0_35.4 (VCC), LED0_36.4 (VCC), LED0_37.4 (VCC), LED0_38.4 (VCC), LED0_39.4 (VCC), LED0_40.4 (VCC); also elsewhere on the board

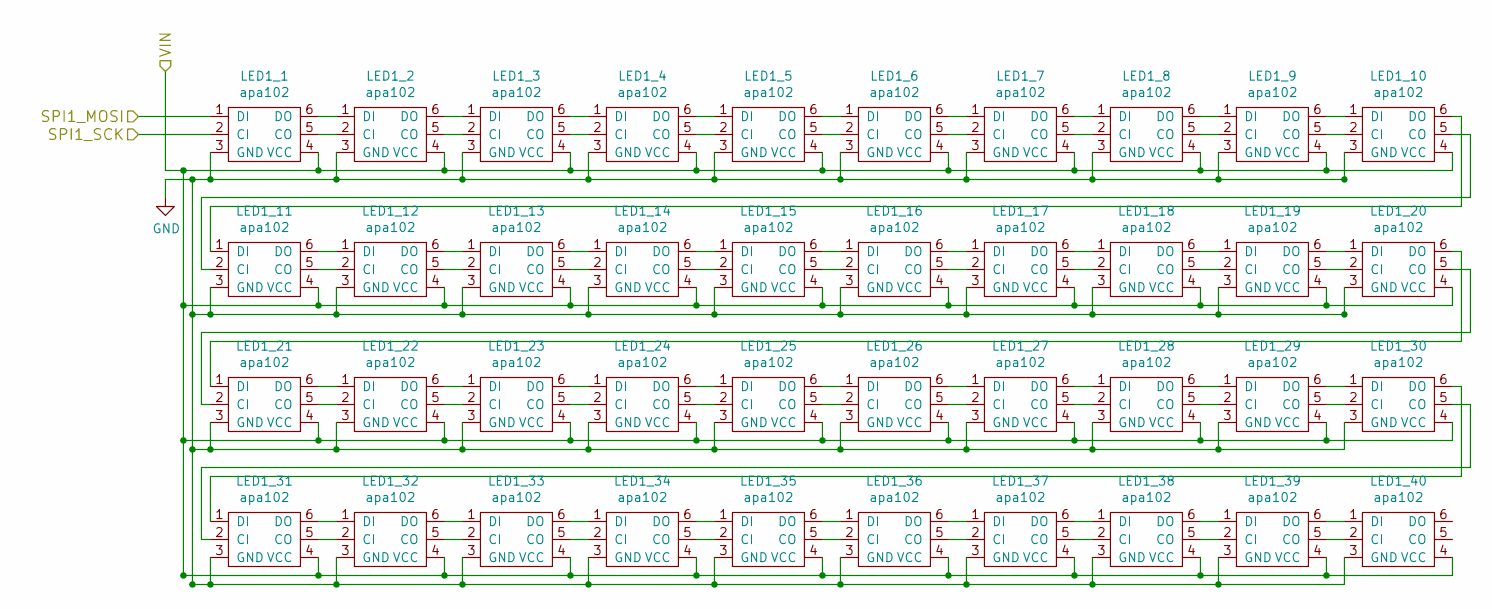
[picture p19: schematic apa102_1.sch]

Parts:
LED1_1, LED1_2, LED1_3, LED1_4, LED1_5, LED1_6, LED1_7, LED1_8, LED1_9, LED1_10, LED1_11, LED1_12, LED1_13, LED1_14, LED1_15, LED1_16, LED1_17, LED1_18, LED1_19, LED1_20, LED1_21, LED1_22, LED1_23, LED1_24, LED1_25, LED1_26, LED1_27, LED1_28, LED1_29, LED1_30, LED1_31, LED1_32, LED1_33, LED1_34, LED1_35, LED1_36, LED1_37, LED1_38, LED1_39, LED1_40: apa102

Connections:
APA102_1_MOSI: LED1_1.1 (DI); also elsewhere on the board
APA102_1_SCK: LED1_1.2 (CI); also elsewhere on the board
GND: LED1_1.3 (GND), LED1_2.3 (GND), LED1_3.3 (GND), LED1_4.3 (GND), LED1_5.3 (GND), LED1_6.3 (GND), LED1_7.3 (GND), LED1_8.3 (GND), LED1_9.3 (GND), LED1_10.3 (GND), LED1_11.3 (GND), LED1_12.3 (GND), LED1_13.3 (GND), LED1_14.3 (GND), LED1_15.3 (GND), LED1_16.3 (GND), LED1_17.3 (GND), LED1_18.3 (GND), LED1_19.3 (GND), LED1_20.3 (GND), LED1_21.3 (GND), LED1_22.3 (GND), LED1_23.3 (GND), LED1_24.3 (GND), LED1_25.3 (GND), LED1_26.3 (GND), LED1_27.3 (GND), LED1_28.3 (GND), LED1_29.3 (GND), LED1_30.3 (GND), LED1_31.3 (GND), LED1_32.3 (GND), LED1_33.3 (GND), LED1_34.3 (GND), LED1_35.3 (GND), LED1_36.3 (GND), LED1_37.3 (GND), LED1_38.3 (GND), LED1_39.3 (GND), LED1_40.3 (GND); also elsewhere on the board
unnamed: LED1_1.5 (CO), LED1_2.2 (CI)
unnamed: LED1_1.6 (DO), LED1_2.1 (DI)
unnamed: LED1_2.5 (CO), LED1_3.2 (CI)
unnamed: LED1_2.6 (DO), LED1_3.1 (DI)
unnamed: LED1_3.5 (CO), LED1_4.2 (CI)
unnamed: LED1_3.6 (DO), LED1_4.1 (DI)
unnamed: LED1_4.5 (CO), LED1_5.2 (CI)
unnamed: LED1_4.6 (DO), LED1_5.1 (DI)
unnamed: LED1_5.5 (CO), LED1_6.2 (CI)
unnamed: LED1_5.6 (DO), LED1_6.1 (DI)
unnamed: LED1_6.5 (CO), LED1_7.2 (CI)
unnamed: LED1_6.6 (DO), LED1_7.1 (DI)
unnamed: LED1_7.5 (CO), LED1_8.2 (CI)
unnamed: LED1_7.6 (DO), LED1_8.1 (DI)
unnamed: LED1_8.5 (CO), LED1_9.2 (CI)
unnamed: LED1_8.6 (DO), LED1_9.1 (DI)
unnamed: LED1_9.6 (DO), LED1_10.1 (DI)
unnamed: LED1_9.5 (CO), LED1_10.2 (CI)
unnamed: LED1_10.5 (CO), LED1_11.2 (CI)
unnamed: LED1_10.6 (DO), LED1_11.1 (DI)
unnamed: LED1_11.5 (CO), LED1_12.2 (CI)
unnamed: LED1_11.6 (DO), LED1_12.1 (DI)
unnamed: LED1_12.5 (CO), LED1_13.2 (CI)
unnamed: LED1_12.6 (DO), LED1_13.1 (DI)
unnamed: LED1_13.5 (CO), LED1_14.2 (CI)
unnamed: LED1_13.6 (DO), LED1_14.1 (DI)
unnamed: LED1_14.5 (CO), LED1_15.2 (CI)
unnamed: LED1_14.6 (DO), LED1_15.1 (DI)
unnamed: LED1_15.5 (CO), LED1_16.2 (CI)
unnamed: LED1_15.6 (DO), LED1_16.1 (DI)
unnamed: LED1_16.5 (CO), LED1_17.2 (CI)
unnamed: LED1_16.6 (DO), LED1_17.1 (DI)
unnamed: LED1_17.5 (CO), LED1_18.2 (CI)
unnamed: LED1_17.6 (DO), LED1_18.1 (DI)
unnamed: LED1_18.5 (CO), LED1_19.2 (CI)
unnamed: LED1_18.6 (DO), LED1_19.1 (DI)
unnamed: LED1_19.5 (CO), LED1_20.2 (CI)
unnamed: LED1_19.6 (DO), LED1_20.1 (DI)
unnamed: LED1_20.5 (CO), LED1_21.2 (CI)
unnamed: LED1_20.6 (DO), LED1_21.1 (DI)
unnamed: LED1_21.5 (CO), LED1_22.2 (CI)
unnamed: LED1_21.6 (DO), LED1_22.1 (DI)
unnamed: LED1_22.5 (CO), LED1_23.2 (CI)
unnamed: LED1_22.6 (DO), LED1_23.1 (DI)
unnamed: LED1_23.5 (CO), LED1_24.2 (CI)
unnamed: LED1_23.6 (DO), LED1_24.1 (DI)
unnamed: LED1_24.5 (CO), LED1_25.2 (CI)
unnamed: LED1_24.6 (DO), LED1_25.1 (DI)
unnamed: LED1_25.5 (CO), LED1_26.2 (CI)
unnamed: LED1_25.6 (DO), LED1_26.1 (DI)
unnamed: LED1_26.5 (CO), LED1_27.2 (CI)
unnamed: LED1_26.6 (DO), LED1_27.1 (DI)
unnamed: LED1_27.5 (CO), LED1_28.2 (CI)
unnamed: LED1_27.6 (DO), LED1_28.1 (DI)
unnamed: LED1_28.5 (CO), LED1_29.2 (CI)
unnamed: LED1_28.6 (DO), LED1_29.1 (DI)
unnamed: LED1_29.5 (CO), LED1_30.2 (CI)
unnamed: LED1_29.6 (DO), LED1_30.1 (DI)
unnamed: LED1_30.5 (CO), LED1_31.2 (CI)
unnamed: LED1_30.6 (DO), LED1_31.1 (DI)
unnamed: LED1_31.5 (CO), LED1_32.2 (CI)
unnamed: LED1_31.6 (DO), LED1_32.1 (DI)
unnamed: LED1_32.5 (CO), LED1_33.2 (CI)
unnamed: LED1_32.6 (DO), LED1_33.1 (DI)
unnamed: LED1_33.5 (CO), LED1_34.2 (CI)
unnamed: LED1_33.6 (DO), LED1_34.1 (DI)
unnamed: LED1_34.5 (CO), LED1_35.2 (CI)
unnamed: LED1_34.6 (DO), LED1_35.1 (DI)
unnamed: LED1_35.5 (CO), LED1_36.2 (CI)
unnamed: LED1_35.6 (DO), LED1_36.1 (DI)
unnamed: LED1_36.5 (CO), LED1_37.2 (CI)
unnamed: LED1_36.6 (DO), LED1_37.1 (DI)
unnamed: LED1_37.5 (CO), LED1_38.2 (CI)
unnamed: LED1_37.6 (DO), LED1_38.1 (DI)
unnamed: LED1_38.5 (CO), LED1_39.2 (CI)
unnamed: LED1_38.6 (DO), LED1_39.1 (DI)
unnamed: LED1_39.5 (CO), LED1_40.2 (CI)
unnamed: LED1_39.6 (DO), LED1_40.1 (DI)
VIN: LED1_1.4 (VCC), LED1_2.4 (VCC), LED1_3.4 (VCC), LED1_4.4 (VCC), LED1_5.4 (VCC), LED1_6.4 (VCC), LED1_7.4 (VCC), LED1_8.4 (VCC), LED1_9.4 (VCC), LED1_10.4 (VCC), LED1_11.4 (VCC), LED1_12.4 (VCC), LED1_13.4 (VCC), LED1_14.4 (VCC), LED1_15.4 (VCC), LED1_16.4 (VCC), LED1_17.4 (VCC), LED1_18.4 (VCC), LED1_19.4 (VCC), LED1_20.4 (VCC), LED1_21.4 (VCC), LED1_22.4 (VCC), LED1_23.4 (VCC), LED1_24.4 (VCC), LED1_25.4 (VCC), LED1_26.4 (VCC), LED1_27.4 (VCC), LED1_28.4 (VCC), LED1_29.4 (VCC), LED1_30.4 (VCC), LED1_31.4 (VCC), LED1_32.4 (VCC), LED1_33.4 (VCC), LED1_34.4 (VCC), LED1_35.4 (VCC), LED1_36.4 (VCC), LED1_37.4 (VCC), LED1_38.4 (VCC), LED1_39.4 (VCC), LED1_40.4 (VCC); also elsewhere on the board

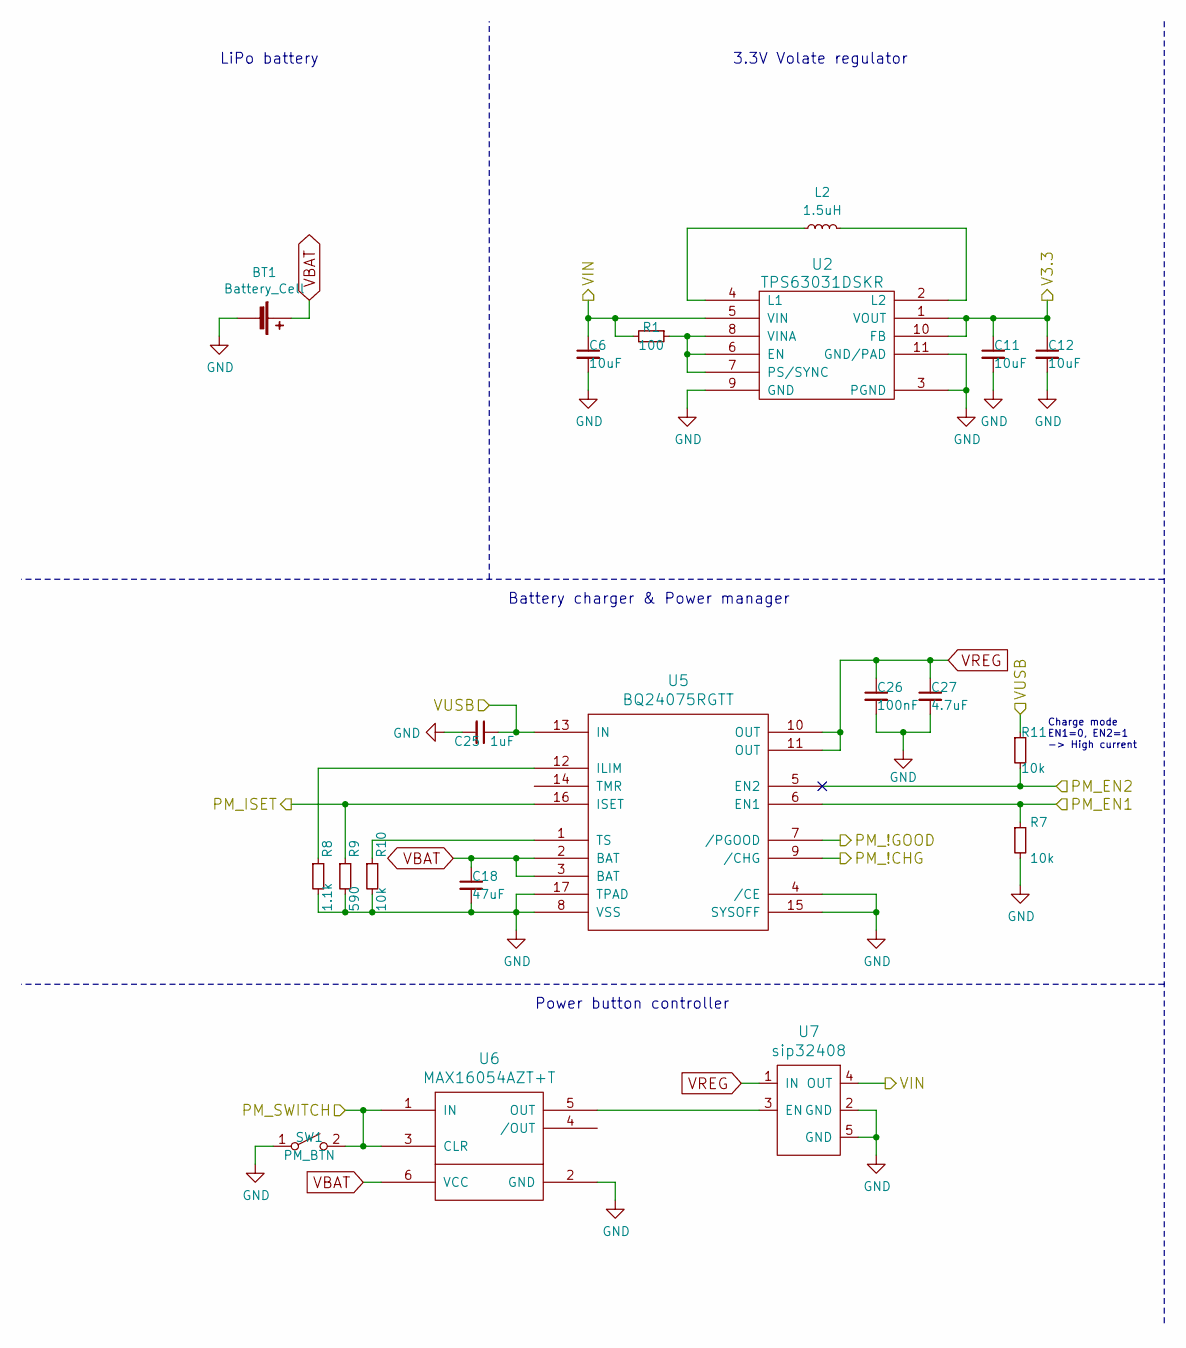
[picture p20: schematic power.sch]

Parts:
BT1: Battery_Cell; 16650_in_pcb_socket
C6, C11, C12: 10uF; C_0603
C18: 47uF; C_0805
C25: 1uF; C_0402
C26: 100nF; C_0402
C27: 4.7uF; C_0402
L2: 1.5uH; R_1206
R1: 100; R_0603
R7, R10, R11: 10k; R_0603
R8: 1.1k; R_0603
R9: 590; R_0603
SW1: PM_BTN; KSS241GLFS
U2: TPS63031DSKR; VSON-10
U5: BQ24075RGTT; QFN-16-1EP_3x3mm_Pitch0.5mm
U6: MAX16054AZT+T; SOT23-6
U7: sip32408

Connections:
GND: BT1.2 (-), C6.2, C11.2, C12.2, C18.2, C25.2, C26.2, C27.2, R7.2, R8.2, R9.2, R10.2, SW1.1 (A), U2.3 (PGND), U2.9 (GND), U2.11 (GND/PAD), U5.4 (/CE), U5.8 (VSS), U5.15 (SYSOFF), U5.17 (TPAD), U6.2 (GND), U7.2 (GND), U7.5 (GND); also elsewhere on the board
unnamed: L2.1, U2.4 (L1)
unnamed: L2.2, U2.2 (L2)
unnamed: R1.1, U2.6 (EN), U2.7 (PS/SYNC), U2.8 (VINA)
unnamed: R8.1, U5.12 (ILIM)
unnamed: R10.1, U5.1 (TS)
unnamed: U6.5 (OUT), U7.3 (EN)
PM_!CHG: U5.9 (/CHG); also elsewhere on the board
PM_!GOOD: U5.7 (/PGOOD); also elsewhere on the board
PM_EN1: R7.1, U5.6 (EN1); also elsewhere on the board
PM_EN2: R11.2, U5.5 (EN2); also elsewhere on the board
PM_ISET: R9.1, U5.16 (ISET); also elsewhere on the board
PM_SWITCH: SW1.2 (B), U6.1 (IN), U6.3 (CLR); also elsewhere on the board
V3.3: C11.1, C12.1, U2.1 (VOUT), U2.10 (FB); also elsewhere on the board
VBAT: BT1.1 (+), C18.1, U5.2 (BAT), U5.3 (BAT), U6.6 (VCC)
VIN: C6.1, R1.2, U2.5 (VIN), U7.4 (OUT); also elsewhere on the board
VREG: C26.1, C27.1, U5.10 (OUT), U5.11 (OUT), U7.1 (IN)
VUSB: C25.1, R11.1, U5.13 (IN); also elsewhere on the board

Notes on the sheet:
LiPo battery
3.3V Volate regulator
Power button controller
Battery charger & Power manager
Charge mode EN1=0, EN2=1 -> High current

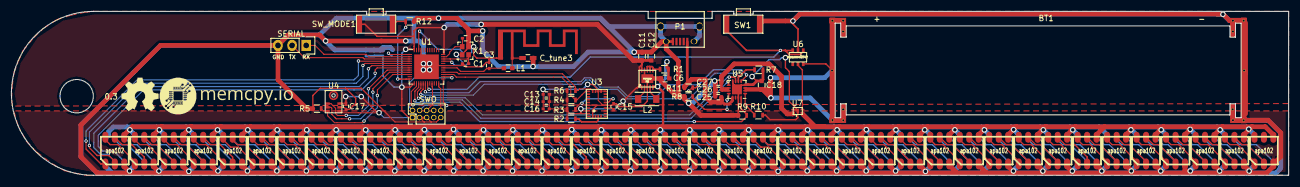
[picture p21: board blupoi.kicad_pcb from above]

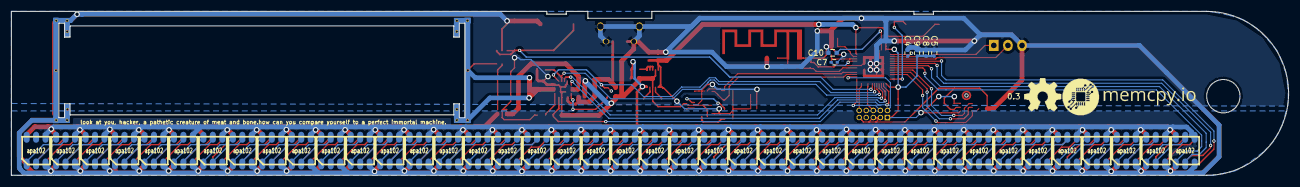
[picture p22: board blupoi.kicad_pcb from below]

Board: 2 copper layers, 229.7 x 29.5 mm, 131 parts (46 on the bottom side), 200 nets.

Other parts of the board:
SERIAL: SERIAL; Pin_Header_Straight_1x03
SWO: CONN_02X05; Pin_Header_Straight_2x05_Pitch1.27mm

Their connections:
GND: SERIAL.3, SWO.3, SWO.5, SWO.9; also elsewhere on the board
RESET: SWO.10; also elsewhere on the board
RX: SERIAL.1; also elsewhere on the board
SWCLK: SWO.4; also elsewhere on the board
SWDIO: SWO.2; also elsewhere on the board
SWO: SWO.6; also elsewhere on the board
TX: SERIAL.2; also elsewhere on the board
V3.3: SWO.1; also elsewhere on the board

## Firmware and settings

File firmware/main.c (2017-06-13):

#include <stdlib.h>

#include "apa102.h"
#include "uart.h"


const uint32_t apa102_0_sck = 2;
const uint32_t apa102_0_mosi = 3;
const uint32_t apa102_1_sck = 4;
const uint32_t apa102_1_mosi = 5;
const uint32_t apa102_nbr_leds = 40;
apa102_t *apa102_0;
apa102_t *apa102_1;


void app_error_fault_handler(uint32_t id, uint32_t pc, uint32_t info)
{
    #ifdef DEBUG
    app_error_print(id, pc, info);
    #endif

    apa102_led_t red = { .a = 32, .r = 255, .g = 0, .b = 0 };
    apa102_setcolor(apa102_0, &red);
    apa102_setcolor(apa102_1, &red);

    while (1);
}

int main(void) {

    /* Setup */
    uart_init(2, 3, 256);
    uart_send("uart_init complete\r\n");
    printf("printf: uart_init complete\r\n");
    apa102_0 = apa102_init(apa102_nbr_leds, apa102_0_sck, apa102_0_mosi);
    apa102_1 = apa102_init(apa102_nbr_leds, apa102_1_sck, apa102_1_mosi);
    apa102_clear(apa102_0);
    apa102_clear(apa102_1);

    apa102_led_t green = { .a = 32, .r = 0, .g = 255, .b = 0 };
    apa102_setcolor(apa102_0, &green);
    apa102_setcolor(apa102_1, &green);
    apa102_send(apa102_0);
    apa102_send(apa102_1);
}

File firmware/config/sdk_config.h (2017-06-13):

#ifndef SDK_CONFIG_H
#define SDK_CONFIG_H

#include "app_config.h"

// <<< Use Configuration Wizard in Context Menu >>>\n
// <h> nRF_Drivers 

//==========================================================
// <e> CLOCK_ENABLED - nrf_drv_clock - CLOCK peripheral driver
//==========================================================
#ifndef CLOCK_ENABLED
#define CLOCK_ENABLED 1
#endif
#if  CLOCK_ENABLED
// <o> CLOCK_CONFIG_XTAL_FREQ  - HF XTAL Frequency
 
// <0=> Default (64 MHz) 

#ifndef CLOCK_CONFIG_XTAL_FREQ
#define CLOCK_CONFIG_XTAL_FREQ 0
#endif

// <o> CLOCK_CONFIG_LF_SRC  - LF Clock Source
 
// <0=> RC 
// <1=> XTAL 
// <2=> Synth 

#ifndef CLOCK_CONFIG_LF_SRC
#define CLOCK_CONFIG_LF_SRC 1
#endif

// <o> CLOCK_CONFIG_IRQ_PRIORITY  - Interrupt priority
 

// <i> Priorities 0,2 (nRF51) and 0,1,4,5 (nRF52) are reserved for SoftDevice
// <0=> 0 (highest) 
// <1=> 1 
// <2=> 2 
// <3=> 3 
// <4=> 4 
// <5=> 5 
// <6=> 6 
// <7=> 7 

#ifndef CLOCK_CONFIG_IRQ_PRIORITY
#define CLOCK_CONFIG_IRQ_PRIORITY 7
#endif

// <e> CLOCK_CONFIG_LOG_ENABLED - Enables logging in the module.
//==========================================================
#ifndef CLOCK_CONFIG_LOG_ENABLED
#define CLOCK_CONFIG_LOG_ENABLED 0
#endif
#if  CLOCK_CONFIG_LOG_ENABLED
// <o> CLOCK_CONFIG_LOG_LEVEL  - Default Severity level
 
// <0=> Off 
// <1=> Error 
// <2=> Warning 
// <3=> Info 
// <4=> Debug 

#ifndef CLOCK_CONFIG_LOG_LEVEL
#define CLOCK_CONFIG_LOG_LEVEL 3
#endif

// <o> CLOCK_CONFIG_INFO_COLOR  - ANSI escape code prefix.
 
// <0=> Default 
// <1=> Black 
// <2=> Red 
// <3=> Green 
// <4=> Yellow 
// <5=> Blue 
// <6=> Magenta 
// <7=> Cyan 
// <8=> White 

#ifndef CLOCK_CONFIG_INFO_COLOR
#define CLOCK_CONFIG_INFO_COLOR 0
#endif

// <o> CLOCK_CONFIG_DEBUG_COLOR  - ANSI escape code prefix.
 
// <0=> Default 
// <1=> Black 
// <2=> Red 
// <3=> Green 
// <4=> Yellow 
// <5=> Blue 
// <6=> Magenta 
// <7=> Cyan 
// <8=> White 

#ifndef CLOCK_CONFIG_DEBUG_COLOR
#define CLOCK_CONFIG_DEBUG_COLOR 0
#endif

#endif //CLOCK_CONFIG_LOG_ENABLED
// </e>

#endif //CLOCK_ENABLED
// </e>

// <e> GPIOTE_ENABLED - nrf_drv_gpiote - GPIOTE peripheral driver
//==========================================================
#ifndef GPIOTE_ENABLED
#define GPIOTE_ENABLED 1
#endif
#if  GPIOTE_ENABLED
// <o> GPIOTE_CONFIG_NUM_OF_LOW_POWER_EVENTS - Number of lower power input pins 
#ifndef GPIOTE_CONFIG_NUM_OF_LOW_POWER_EVENTS
#define GPIOTE_CONFIG_NUM_OF_LOW_POWER_EVENTS 4
#endif

// <o> GPIOTE_CONFIG_IRQ_PRIORITY  - Interrupt priority
 

// <i> Priorities 0,2 (nRF51) and 0,1,4,5 (nRF52) are reserved for SoftDevice
// <0=> 0 (highest) 
// <1=> 1 
// <2=> 2 
// <3=> 3 
// <4=> 4 
// <5=> 5 
// <6=> 6 
// <7=> 7 

#ifndef GPIOTE_CONFIG_IRQ_PRIORITY
#define GPIOTE_CONFIG_IRQ_PRIORITY 2
#endif

// <e> GPIOTE_CONFIG_LOG_ENABLED - Enables logging in the module.
//==========================================================
#ifndef GPIOTE_CONFIG_LOG_ENABLED
#define GPIOTE_CONFIG_LOG_ENABLED 0
#endif
#if  GPIOTE_CONFIG_LOG_ENABLED
// <o> GPIOTE_CONFIG_LOG_LEVEL  - Default Severity level
 
// <0=> Off 
// <1=> Error 
// <2=> Warning 
// <3=> Info 
// <4=> Debug 

#ifndef GPIOTE_CONFIG_LOG_LEVEL
#define GPIOTE_CONFIG_LOG_LEVEL 3
#endif

// <o> GPIOTE_CONFIG_INFO_COLOR  - ANSI escape code prefix.
 
// <0=> Default 
// <1=> Black 
// <2=> Red 
// <3=> Green 
// <4=> Yellow 
// <5=> Blue 
// <6=> Magenta 
// <7=> Cyan 
// <8=> White 

#ifndef GPIOTE_CONFIG_INFO_COLOR
#define GPIOTE_CONFIG_INFO_COLOR 0
#endif

// <o> GPIOTE_CONFIG_DEBUG_COLOR  - ANSI escape code prefix.
 
// <0=> Default 
// <1=> Black 
// <2=> Red 
// <3=> Green 
// <4=> Yellow 
// <5=> Blue 
// <6=> Magenta 
// <7=> Cyan 
// <8=> White 

#ifndef GPIOTE_CONFIG_DEBUG_COLOR
#define GPIOTE_CONFIG_DEBUG_COLOR 0
#endif

#endif //GPIOTE_CONFIG_LOG_ENABLED
// </e>

#endif //GPIOTE_ENABLED
// </e>

// <e> PERIPHERAL_RESOURCE_SHARING_ENABLED - nrf_drv_common - Peripheral drivers common module
//==========================================================
#ifndef PERIPHERAL_RESOURCE_SHARING_ENABLED
#define PERIPHERAL_RESOURCE_SHARING_ENABLED 0
#endif
#if  PERIPHERAL_RESOURCE_SHARING_ENABLED
// <e> COMMON_CONFIG_LOG_ENABLED - Enables logging in the module.
//==========================================================
#ifndef COMMON_CONFIG_LOG_ENABLED
#define COMMON_CONFIG_LOG_ENABLED 0
#endif
#if  COMMON_CONFIG_LOG_ENABLED
// <o> COMMON_CONFIG_LOG_LEVEL  - Default Severity level
 
// <0=> Off 
// <1=> Error 
// <2=> Warning 
// <3=> Info 
// <4=> Debug 

#ifndef COMMON_CONFIG_LOG_LEVEL
#define COMMON_CONFIG_LOG_LEVEL 3
#endif

// <o> COMMON_CONFIG_INFO_COLOR  - ANSI escape code prefix.
 
// <0=> Default 
// <1=> Black 
// <2=> Red 
// <3=> Green 
// <4=> Yellow 
// <5=> Blue 
// <6=> Magenta 
// <7=> Cyan 
// <8=> White 

#ifndef COMMON_CONFIG_INFO_COLOR
#define COMMON_CONFIG_INFO_COLOR 0
#endif

// <o> COMMON_CONFIG_DEBUG_COLOR  - ANSI escape code prefix.
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

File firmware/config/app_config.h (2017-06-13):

#ifndef APP_CONFIG_H
#define APP_CONFIG_H

#define SPI0_ENABLED 1
#define SPI1_ENABLED 1

#define APP_UART_ENABLED 1
#define RETARGET_ENABLED 1

#endif //APP_CONFIG_H

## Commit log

2016-09-02 Pre rev0.1, layout almost complete
    [apa102_0.sch, apa102_1.sch, blupoi.kicad_pcb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]
2016-09-03 Changed to angled switch
    [blupoi.kicad_pcb, blupoi.sch]
2016-09-03 Moved switch
    [blupoi.kicad_pcb]
2016-09-03 Router all APA102 signal traces
    [blupoi.kicad_pcb]
2016-09-03 Route APA102 VIN traces
    [blupoi.kicad_pcb, blupoi.sch]
2016-09-03 Small PMIC tweaks
    [blupoi.kicad_pcb]
2016-09-03 Reorganized SWO signals
    [blupoi.kicad_pcb]
2016-09-16 Router some APA102 GND traces
    [blupoi.kicad_pcb]
2016-09-20 Removed cp2102 IC
    [apa102_0.sch, apa102_1.sch, blupoi.kicad_pcb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]
2016-09-20 Added GND/VIN copper pour
    [blupoi.kicad_pcb]
2016-09-20 Made trace nicer
    [blupoi.kicad_pcb]
2016-09-20 Moved traces out of the way from antennas
    [blupoi.kicad_pcb]
2016-09-20 Renamed battery holder to BAT
    [blupoi.kicad_pcb]
2016-12-30 Updated HW
    [blupoi.kicad_pcb]
2016-12-30 Added some components
    [blupoi.dsn]
2017-02-05 Add +/- and add missing copper pads
    [blupoi.kicad_pcb]
2017-02-05 Added 16340 battery holder
2017-02-05 Removed ALL tracks
    [blupoi.kicad_pcb]
2017-02-05 Increase MIC hole size
    [blupoi.kicad_pcb]
2017-02-05 Increased MIC pad sizes
    [blupoi.kicad_pcb]
2017-02-06 Removed 72 LEDs
    [apa102_0.sch, apa102_1.sch, blupoi.sch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]
2017-02-06 Longer pads on bno055
    [blupoi.kicad_pcb]
2017-02-06 Add small v0.2 outline
    [outline_small.dxf]
2017-02-06 Power, add pulldown to bq24075 EN1
    [power.sch]
2017-02-06 Power, add pulldown to bq24075 SYSOFF
    [power.sch]
2017-02-14 Added sip32408 footprint
2017-02-14 Shrunk led count in apa102 sub schematic
    [apa102_0.sch, apa102_1.sch]
2017-02-14 Added sip32408 ic
    [blupoi.sch, power.sch]
2017-02-14 Switched to fat small design
    [apa102_0.sch, apa102_1.sch, blupoi.kicad_pcb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]
2017-02-14 Add two missing 3d models
    [blupoi.kicad_pcb]
2017-02-19 Added mode button
    [blupoi.kicad_pcb, blupoi.sch]
2017-02-19 Fixed broken inductor schematic
    [apa102_0.sch, apa102_1.sch, blupoi.kicad_pcb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]
2017-02-19 Change net name from VCHG to VREG
    [blupoi.kicad_pcb, power.sch]
2017-02-19 Fixed SIP32408 footprint pins/pads lacking GND
    [blupoi.kicad_pcb, power.sch]
2017-02-19 Started routing v0.2
    [blupoi.kicad_pcb]
2017-02-20 Started routing v0.2..
    [blupoi.kicad_pcb]
2017-02-20 Fixed APA102 bank 1 SPI trace names
    [apa102_1.sch]
2017-02-20 Started routing v0.2...
    [blupoi.kicad_pcb, blupoi.sch, power.sch]
2017-02-20 Finished routing for v0.2
    [blupoi.kicad_pcb, blupoi.sch]
2017-02-20 Improved routing for v0.2
    [blupoi.kicad_pcb]
2017-02-20 Beefed up BAT USB GND traces
    [blupoi.kicad_pcb]
2017-02-21 Add pin1 indicator to bno055 footprint
    [blupoi.kicad_pcb]
2017-02-21 Add filled zones
    [blupoi.kicad_pcb]
2017-02-21 Add missing 3d model for bno055
    [blupoi.kicad_pcb]
2017-02-21 Generated v0.2 gerbers
    [blupoi-B.Cu.gbl, blupoi-B.Mask.gbs, blupoi-B.SilkS.gbo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]
2017-03-26 Started work on v0.3
    [blupoi.kicad_pcb, outline_small_fat.dxf]
2017-03-26 First draft of v0.3
    [blupoi.kicad_pcb]
2017-03-26 Change C9 footprint C0603->C0402
    [blupoi.kicad_pcb]
2017-03-26 Add v0.3 gerber zip
2017-05-05 Started adding fixes from v0.3 board
2017-05-12 Initial FW build environment import
    [config.txt]
